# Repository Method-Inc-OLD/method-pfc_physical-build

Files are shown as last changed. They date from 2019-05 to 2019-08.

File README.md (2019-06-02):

# Method Personal Food Computer – Physical Build

Documentation of the mechanical and electrical design of [Method](Http://www.method.com)'s Personal Food Computer 

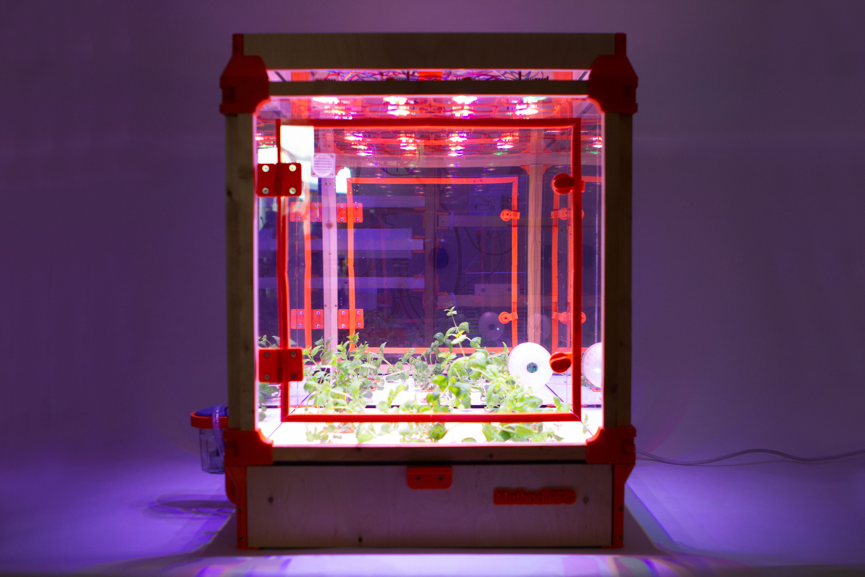
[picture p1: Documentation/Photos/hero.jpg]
mPFC v1.0


## Overview
The Method PFC is a version of OpenAg's Personal Food Computer. It was built to be more modular and incorporate recycled material. This repository contains:
- [Mechanical](/Mechanical) (Construction and 3D prints)
- [Electrical](/Electrical) (Circuitry)

For Method's custom software, please visit the [method-pfc_device-software](http://www.github.com/method-inc/method-pfc_device-software) repository.

## Credits

Method PFC v1.0 was designed and built by David Mayman, Felix Noller, Adrian Kraus, and Luke Thompson in London.

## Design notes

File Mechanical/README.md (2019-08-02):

# Mechanical

## Overview
The chassis is designed around a central 50cm3 acrylic chamber surrounded by a number of modules. All connectors are 3D printed, and all supporting materials are 21mm wood. This design makes it easy to grow or shrink the size of the box for revised designs or differently sized acrylic chambers. We recommend using tough filament. 

The PFC is designed with 4 modules: Bottom, Middle, Top, and Side. Each module has a number of 3D printed connectors. This repository contains 3D Rhino files with individual 3D print blocks, and assemblies for each module as well as one overall assembly.

### Modules
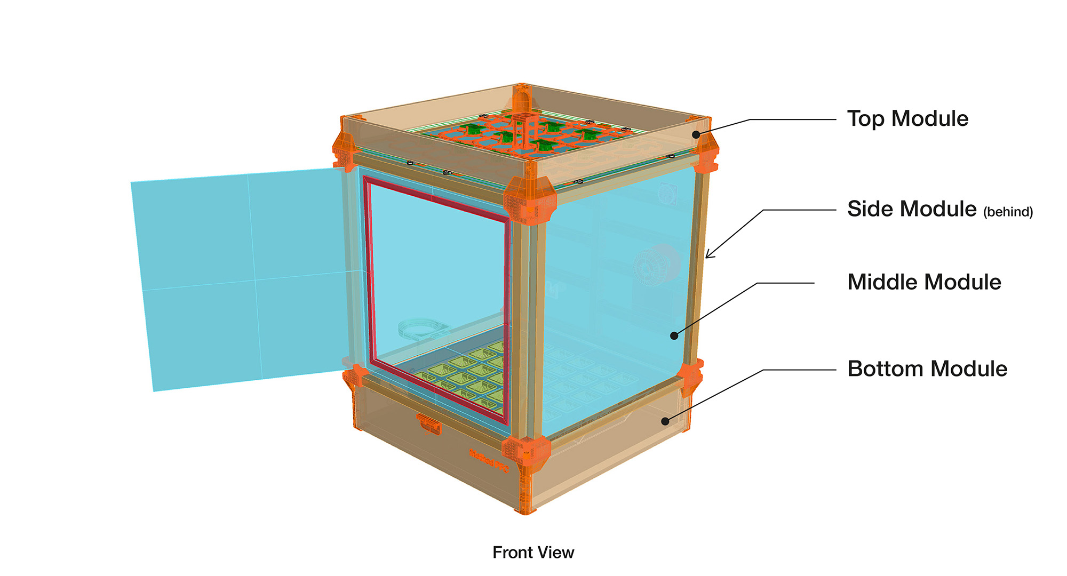
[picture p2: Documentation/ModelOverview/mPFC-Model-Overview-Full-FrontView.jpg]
Full Overview, Front

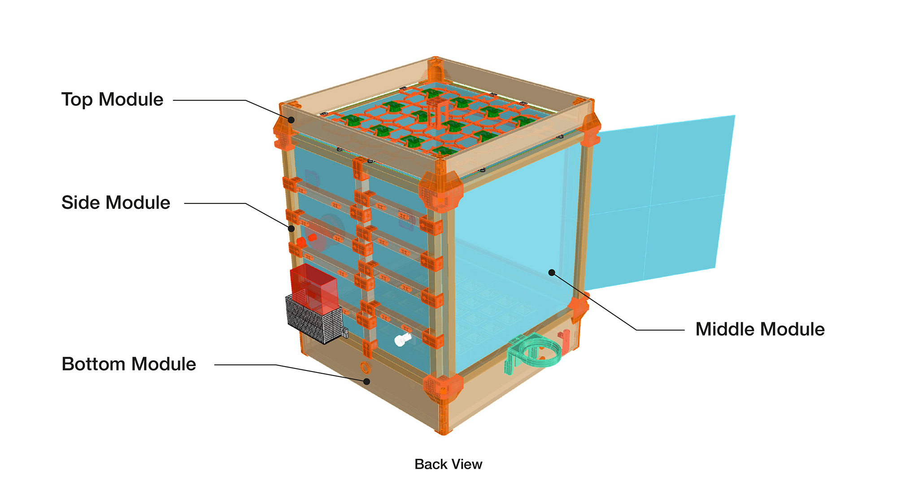
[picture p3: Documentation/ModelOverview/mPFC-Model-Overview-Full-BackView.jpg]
Back Overview, Front

Bottom module
- Component Overview
- Water reservoir
- Air pump
- 3 Atlas sensors (water temp, pH, EC)
- Heating modules glued to water reservoir (in retrospect, these are pretty useless. Most crops require colder water vs warmer.)
- “Feeding tube” / water level indicator
- Humidifier tank, tube, and mount

Middle Module
- Component Overview
- 50cm3 Acrylic chamber (we had one lying around…we realise this isn’t the cheapest item to source new)
- Opaque acrylic base plate to hold crops
- 1 Intake fan and 1 exhaust fan, with duct plates
- Circulation fan
- Air sensor bubble – CO2 and Temperature/humidity sensor
- Door with locks and hinges
- Base plate (for plants), laser-cut acrylic
- 2 way mirror film on the inside face of the acrylic chamber

Top module
- Component Overview
- 12 custom LED board assemblies (3 LEDs per board)
- Top view camera

Side module
- Component Overview
- Custom Mainboard (ended up not being so useful...see electronics)
- PSU
- 2 custom LED power boards (3 channels per)
- Beaglebone
- Arduino Mega
- Relay Board
- Breadboard
- A ton of wiring

## Guide to 3D Prints
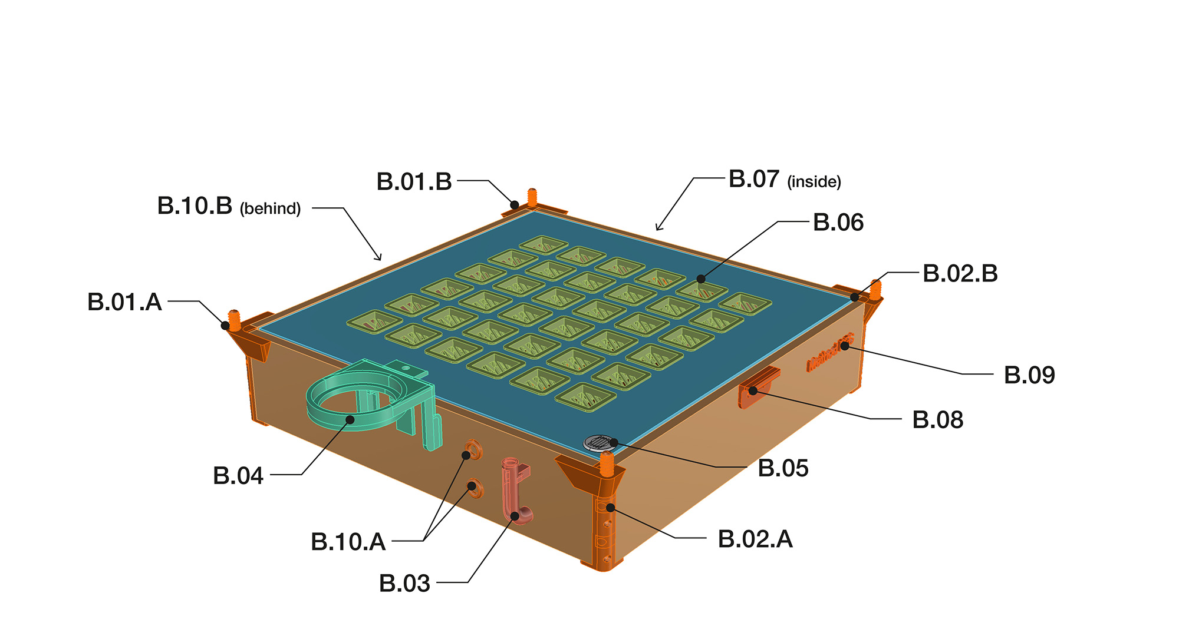
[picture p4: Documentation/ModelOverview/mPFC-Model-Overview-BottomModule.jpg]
Bottom Module Overview

### [Bottom module](/Mechanical/Bottom%20Module)
- B.01.A - Bottom Corner Connector, Left (1)
- B.01.B - Bottom Corner Connector, Right (1)
- B.02.A - Bottom Corner Connector, Door, Left (1)
- B.02.B - Bottom Corner Connector, Door, Right (1)
- B.03 - Feeding Tube Holder (1)
- B.04 - Humidifier Tank Mount (1)
- B.05 - Humidifier Mount (1) [2 versions]
- B.06 - Rockwool Carriage (4-12)
- B.07 - Atlas Sensor Holder (1)
- B.08 - Door Handle (1)
- B.09 - Name plate (1)
- B.10.A - Rivet, Small, for Tubing (2)
- B.10.B - Rivet, Large, for Wiring (1)
- B.11 - Safety Cover (1)
---

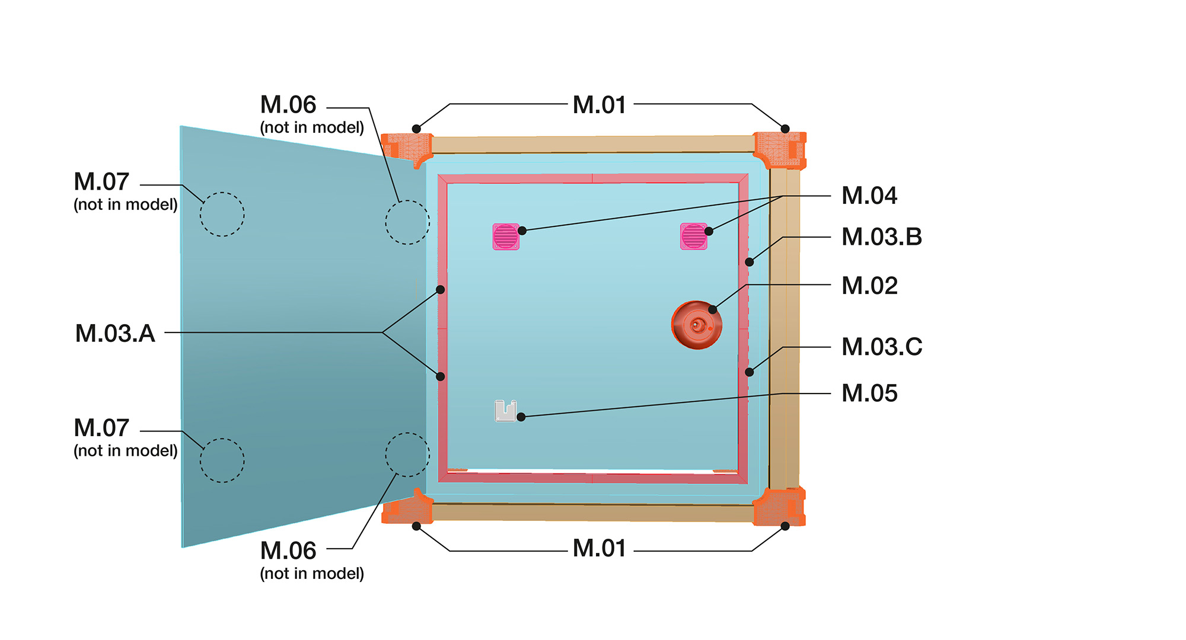
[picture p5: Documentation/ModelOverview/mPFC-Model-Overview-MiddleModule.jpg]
Middle Module Overview

### [Middle module](/Mechanical/Middle%20Module)
- M.01 - Middle Corner Connector (8)
- M.02 - Air Sensor Bubble (1)
- M.03.A - Frame Edge (6)
- M.03.B - Frame Edge, Top Right (1)
- M.03.C - Frame Edge, Bottom Right (1)
- M.04 - Fan Duct (2)
- M.05 - Circulation Fan Mount (1)
- M.06 - Door Hinge (2)
- M.07 - Door Lock (2) [Locking and handle versions]
---

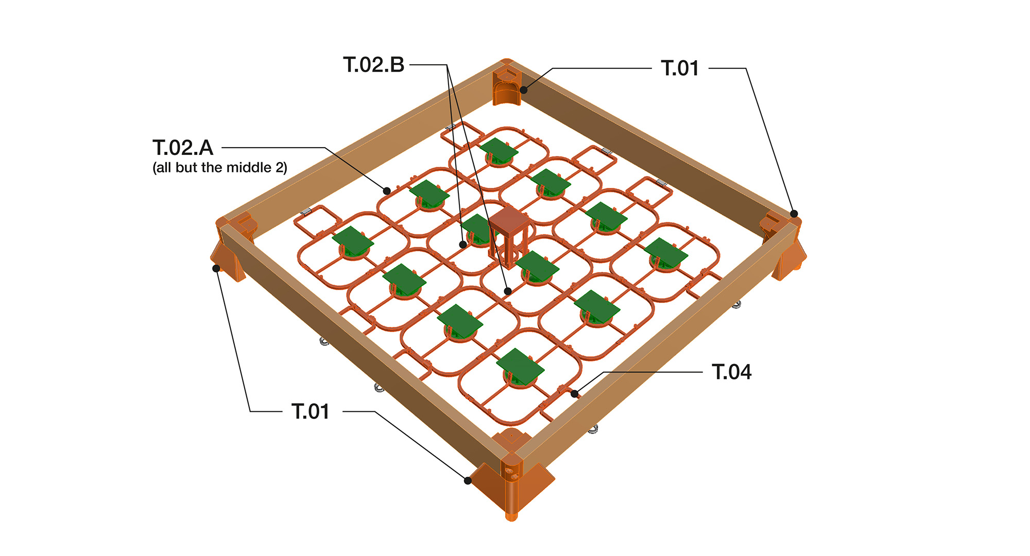
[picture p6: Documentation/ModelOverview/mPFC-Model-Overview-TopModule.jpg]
Top Module Overview

### [Top module](/Mechanical/Top%20Module)
- T.01 - Top Corner Connector (4)
- T.02.A - Lighting Board Mount (10)
- T.02.B - Lighting Board Mount, Camera Holder (2)
- T.03 - Middle Support Cap
- T.04 - Top Edge Spacer (8)
---

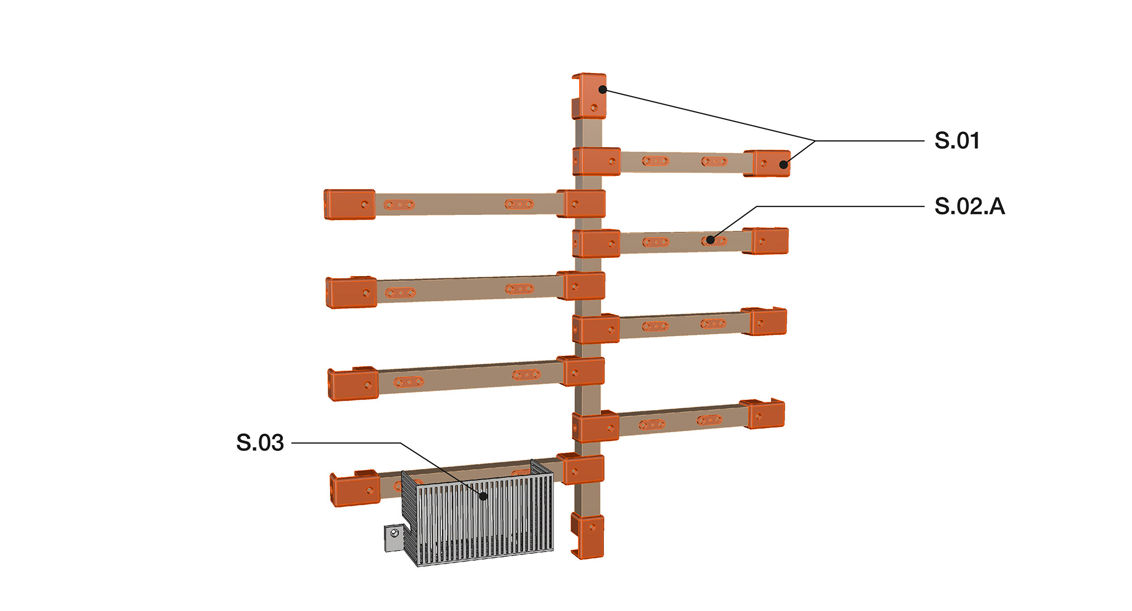
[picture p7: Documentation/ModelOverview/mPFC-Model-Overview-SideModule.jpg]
Side Module Overview

### [Side module](/Mechanical/Side%20Module)
- S.01 - Side Module Connector (16)
- S.02.A - Nut Holder (16)
- S.02.B - Nut Holder, Large (5)
- S.03 - Safety Cover (1)
---

### [Various](/Mechanical/Various)
- V.01 - Screw Nut (8)
- V.02 - Master Key (1)

## Credits

Method PFC v1.0 mechanical designed by Felix Noller and David Mayman

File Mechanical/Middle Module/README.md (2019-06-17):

# Middle Module

View these files as Rhino Source Files or STL files for 3D printing.

Middle Module Overview
- M.01 - Middle Corner Connector (8)
- M.02 - Air Sensor Bubble (1)
- M.03.A - Frame Edge (6)
- M.03.B - Frame Edge, Top Right (1)
- M.03.C - Frame Edge, Bottom Right (1)
- M.04 - Fan Duct (2)
- M.05 - Circulation Fan Mount (1)
- M.06 - Door Hinge (2)
- M.07 - Door Lock (2) [Locking and handle versions]

## Credits

Method PFC v1.0 mechanical designed by Felix Noller and David Mayman

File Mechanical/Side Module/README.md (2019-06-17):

# Side Module

View these files as Rhino Source Files or STL files for 3D printing.

Side Module Overview
- S.01 - Side Module Connector (16)
- S.02.A - Nut Holder (16)
- S.02.B - Nut Holder, Large (5)
- S.03 - Safety Cover (1)

## Credits

Method PFC v1.0 mechanical designed by Felix Noller and David Mayman

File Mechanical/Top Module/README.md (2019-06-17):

# Top Module

View these files as Rhino Source Files or STL files for 3D printing.

Top Module Overview
- T.01 - Top Corner Connector (4)
- T.02.A - Lighting Board Mount (10)
- T.02.B - Lighting Board Mount, Camera Holder (2)
- T.03 - Middle Support Cap
- T.04 - Top Edge Spacer (8)

## Credits

Method PFC v1.0 mechanical designed by Felix Noller and David Mayman

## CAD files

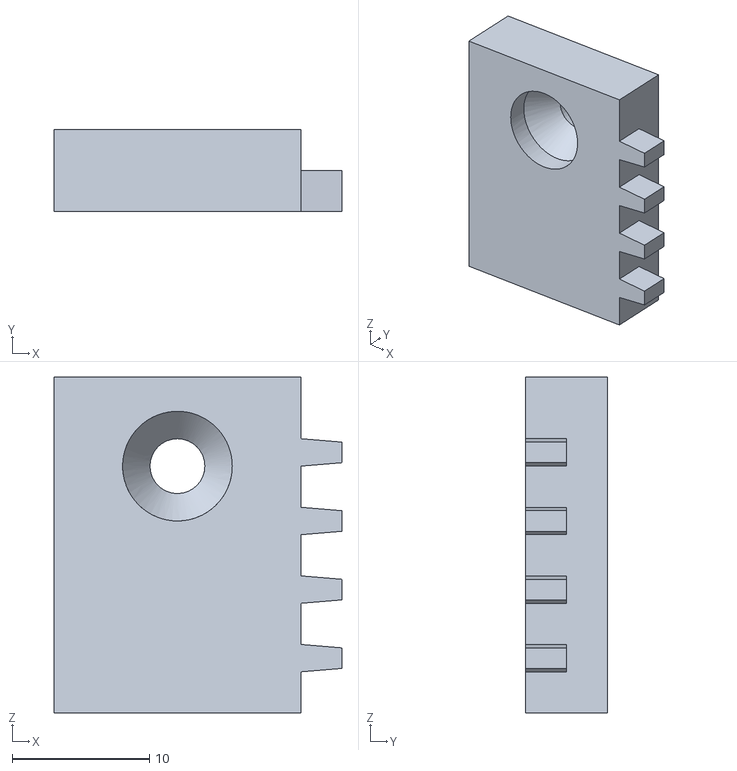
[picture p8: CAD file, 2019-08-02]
Mechanical/Bottom Module/STL for 3D Printing/B.11 - Bottom Module – Safety Cover – Mount Piece L.stl
21.0 x 6.00 x 24.5

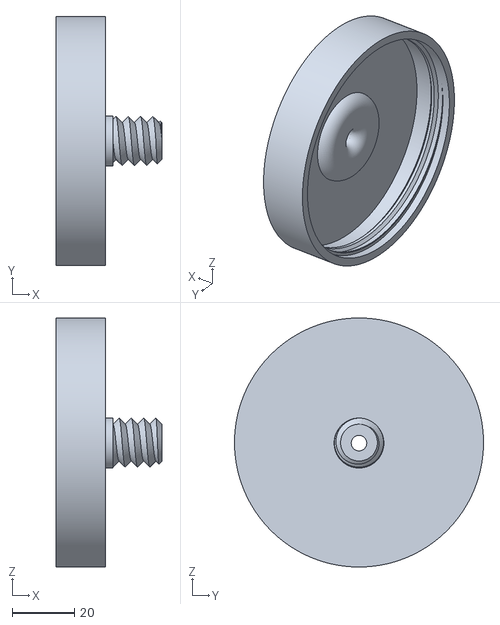
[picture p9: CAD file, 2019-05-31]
Mechanical/Middle Module/STL for 3D printing/M.02 - Air Sensor Bubble (2 of 3).stl
34.1 x 80.0 x 80.0

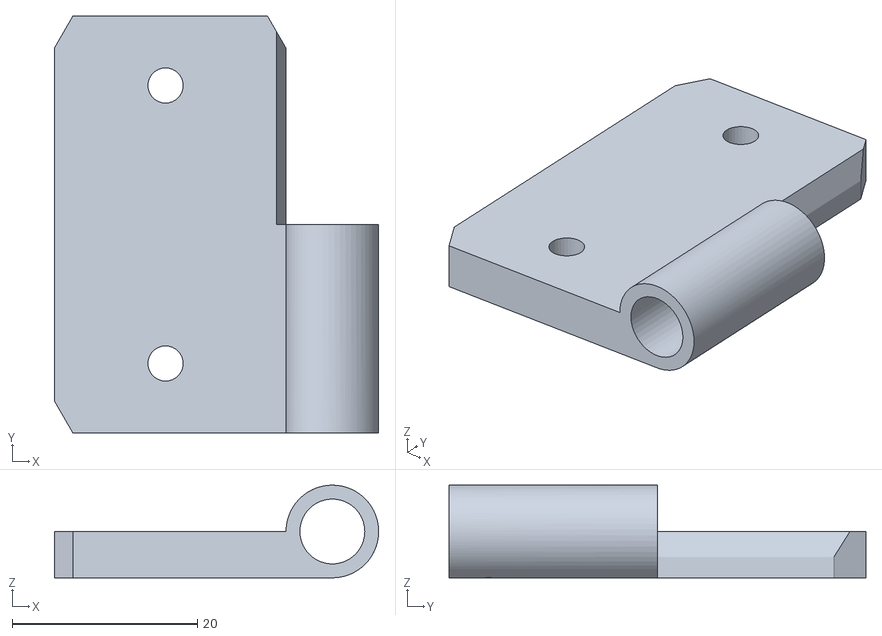
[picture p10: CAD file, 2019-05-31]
Mechanical/Middle Module/STL for 3D printing/M.06 - Door Hinge/files/hinge_frame_side.stl
35.0 x 45.0 x 10.00

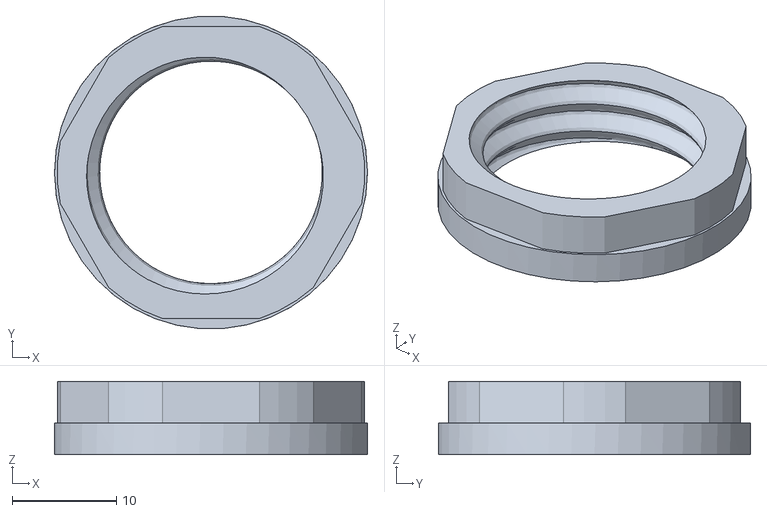
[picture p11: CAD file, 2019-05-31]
Mechanical/Middle Module/STL for 3D printing/M.07 - Door Lock /files/Fecho_002.stl
30.0 x 29.9 x 7.00

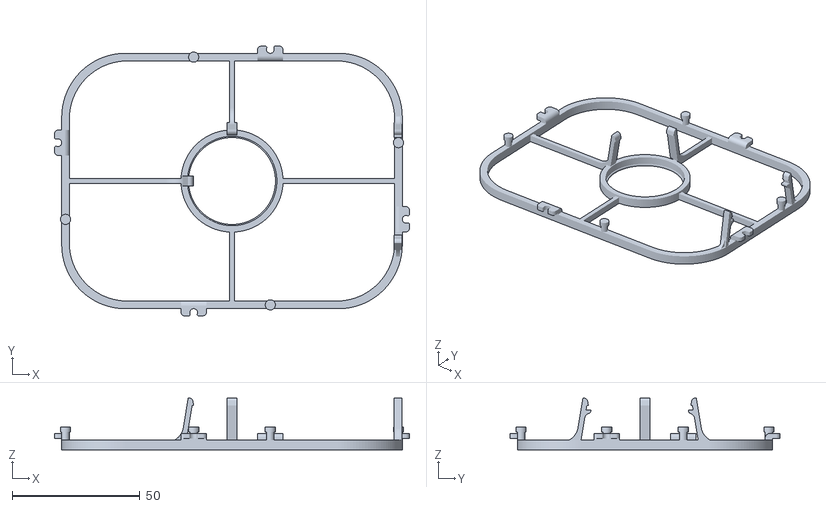
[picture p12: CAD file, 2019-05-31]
Mechanical/Top Module/STL for 3D Printing/T.02.C - Lighting Board Mount, LED Driver Holder.stl
139.0 x 105.6 x 20.3

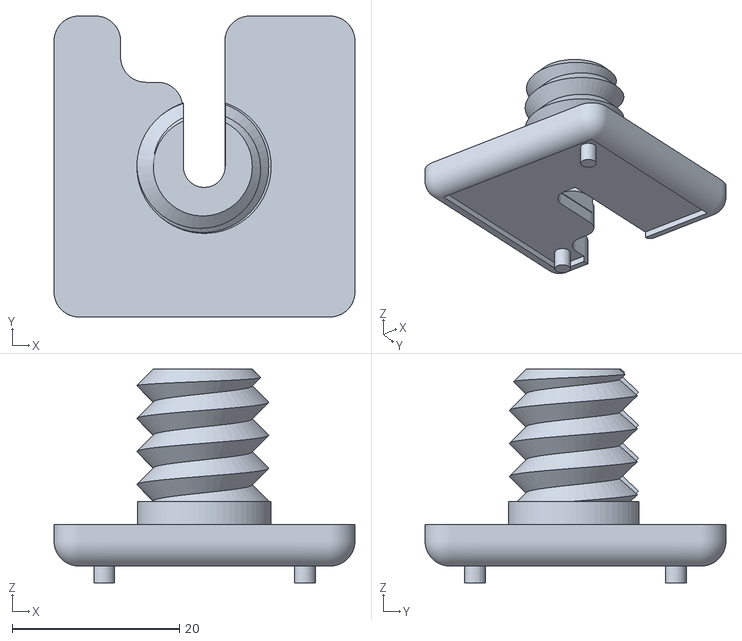
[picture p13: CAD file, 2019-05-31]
Mechanical/Middle Module/STL for 3D printing/M.05 - Circulation Fan Mount (1 of 2).stl
36.0 x 36.0 x 25.6

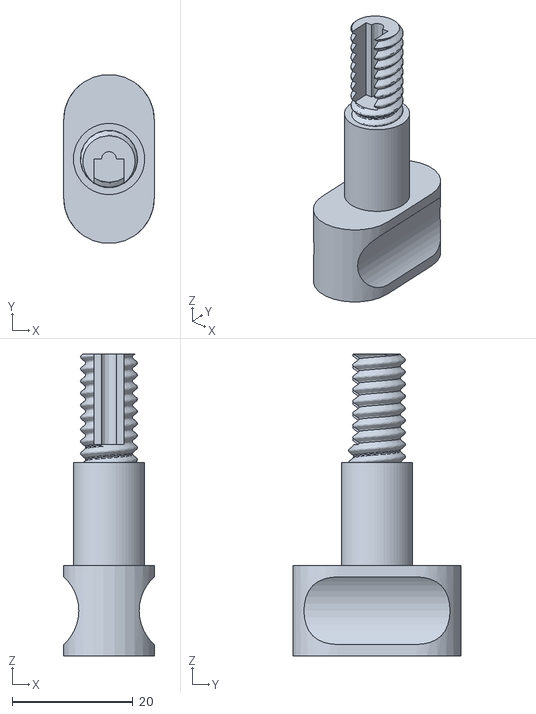
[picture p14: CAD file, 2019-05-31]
Mechanical/Middle Module/STL for 3D printing/M.07 - Door Lock /files/Fecho_003-16-DM.stl
15.0 x 27.9 x 50.0

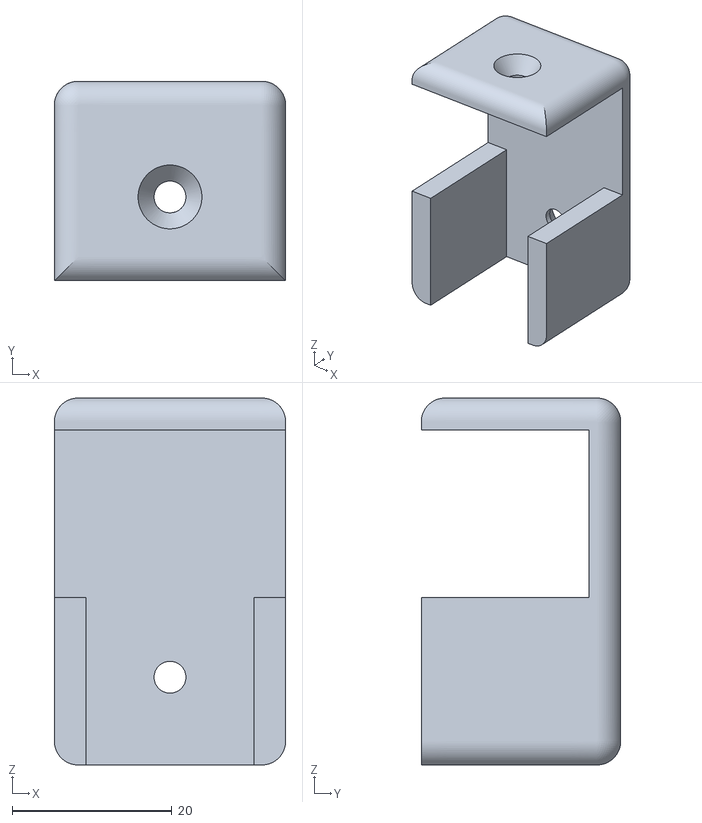
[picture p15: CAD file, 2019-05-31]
Mechanical/Side Module/STL for 3D Printing/S.01 - Side Module Connector.stl
29.0 x 25.0 x 46.0

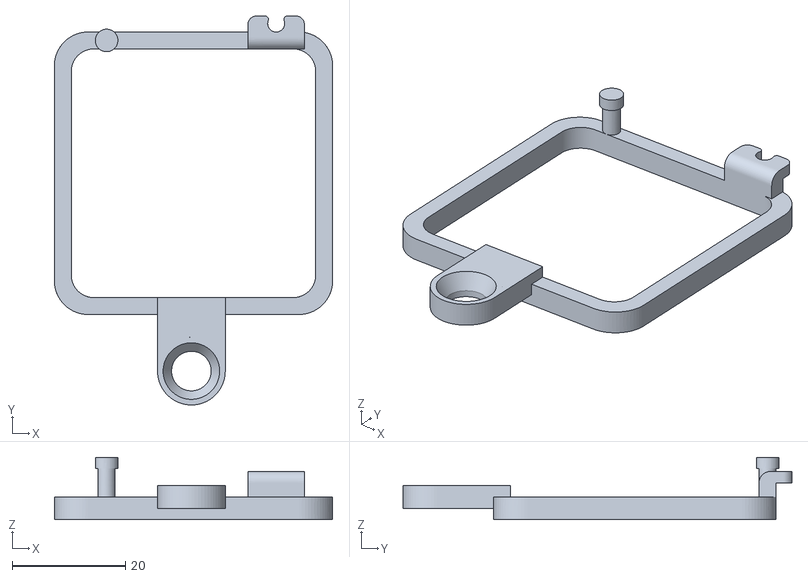
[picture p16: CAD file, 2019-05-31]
Mechanical/Top Module/STL for 3D Printing/T.04 - Top Edge Spacer.stl
49.2 x 68.8 x 11.0

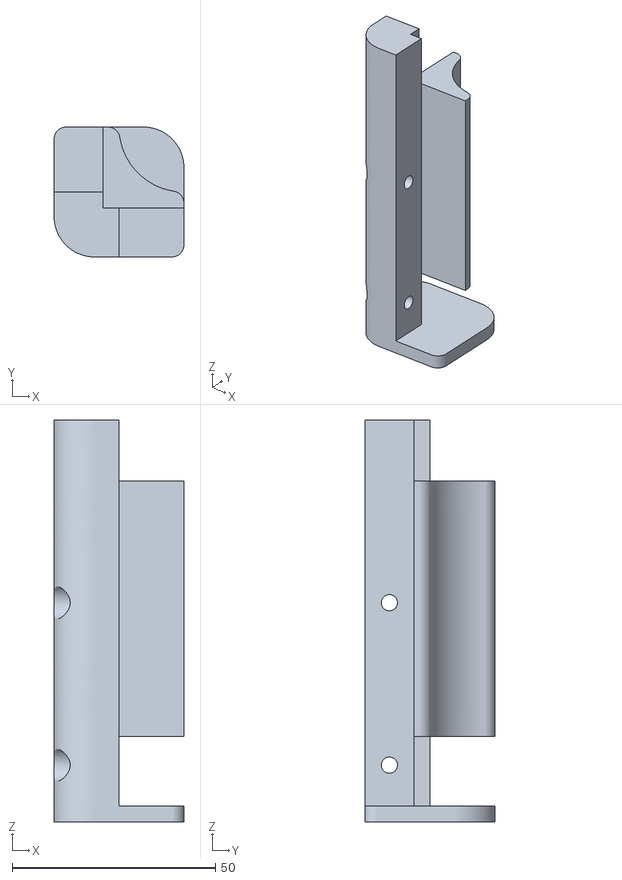
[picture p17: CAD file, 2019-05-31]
Mechanical/Bottom Module/STL for 3D Printing/B.02.B - Bottom Corner Connector, Door, Right (2 of 2).stl
32.0 x 32.0 x 99.0

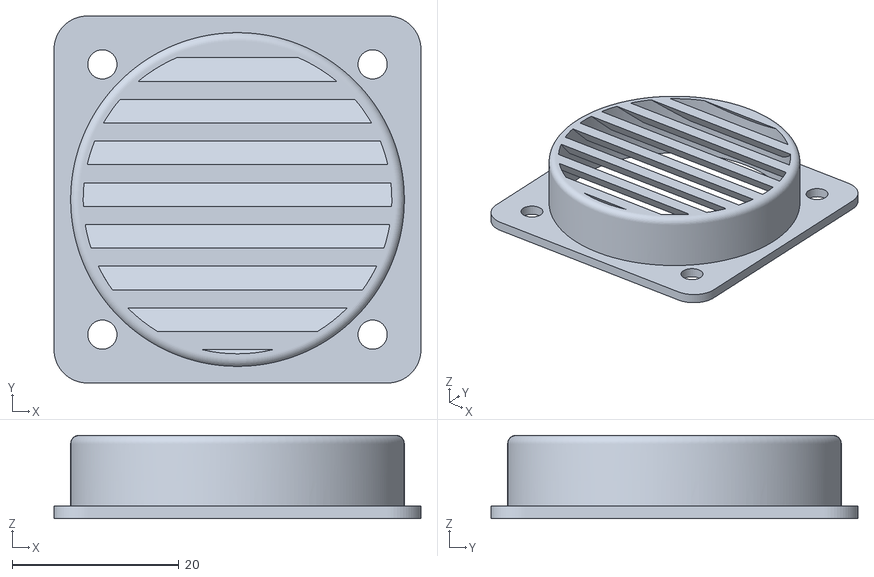
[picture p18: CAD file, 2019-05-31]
Mechanical/Middle Module/STL for 3D printing/M.04 - Fan Duct.stl
44.0 x 44.0 x 10.0

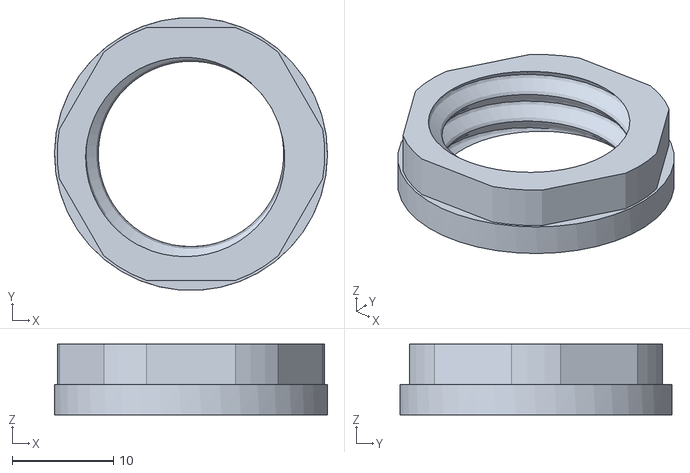
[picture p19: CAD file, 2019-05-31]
Mechanical/Middle Module/STL for 3D printing/M.07 - Door Lock /files/Fecho_002-18.stl
27.0 x 26.9 x 7.00

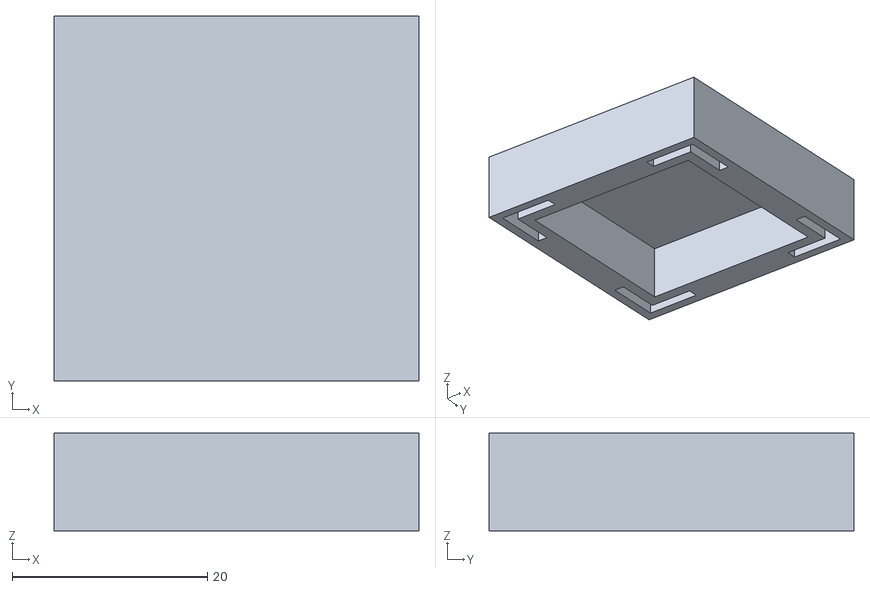
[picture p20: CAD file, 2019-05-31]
Mechanical/Top Module/STL for 3D Printing/T.03 - Middle Support Cap.stl
37.4 x 37.4 x 10.0

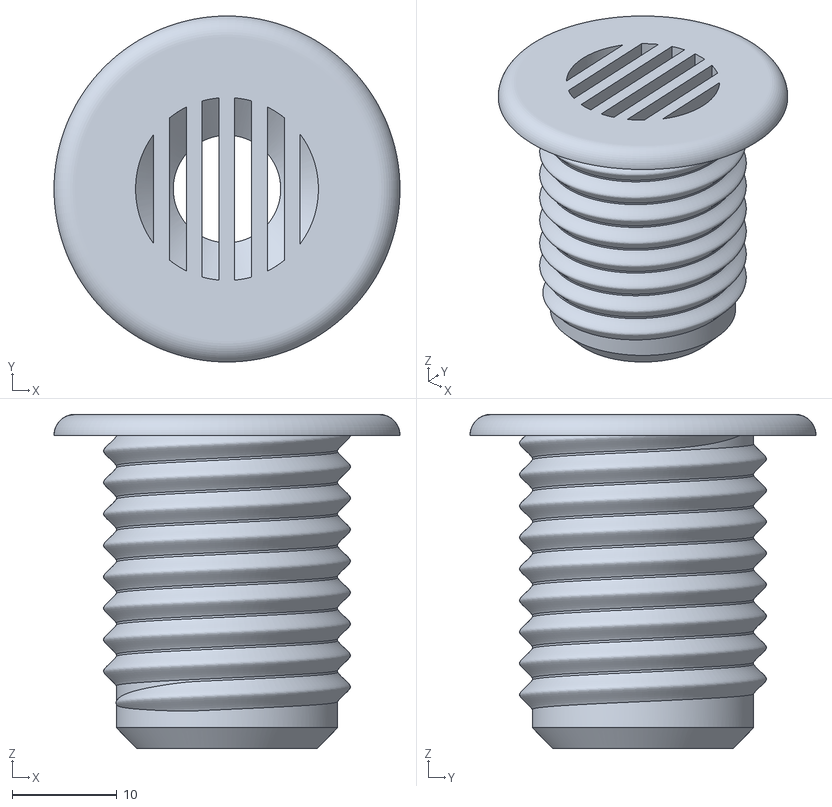
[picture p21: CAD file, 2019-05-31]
Mechanical/Bottom Module/STL for 3D Printing/B.05v2 - Humidifier Mount (1 of 2).stl
33.0 x 33.0 x 31.9

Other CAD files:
Mechanical/Side Module/STL for 3D Printing/S.03 - Safety Cover (3 of 3).stl
Mechanical/Bottom Module/STL for 3D Printing/B.11 - Bottom Module – Safety Cover – Mount Piece R.stl
Mechanical/Middle Module/STL for 3D printing/M.06 - Door Hinge/files/hinge_door_side.stl
Mechanical/Middle Module/STL for 3D printing/M.05 - Circulation Fan Mount (2 of 2).stl
Mechanical/Bottom Module/Rhino Source Files/B.01.A - Bottom Corner Connector, Left.3dm
Mechanical/Bottom Module/Rhino Source Files/B.01.B - Bottom Corner Connector, Right.3dm
Mechanical/Bottom Module/Rhino Source Files/B.010.A - Rivet, Small, for Tubing.3dm
Mechanical/Bottom Module/Rhino Source Files/B.04 - Humidifier Tank Mount.3dm
Mechanical/Bottom Module/Rhino Source Files/B.07 - Atlas Sensor Holder.3dm
Mechanical/Bottom Module/Rhino Source Files/B.08 - Door Handle.3dm
Mechanical/Bottom Module/Rhino Source Files/B.09 - Name plate.3dm
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

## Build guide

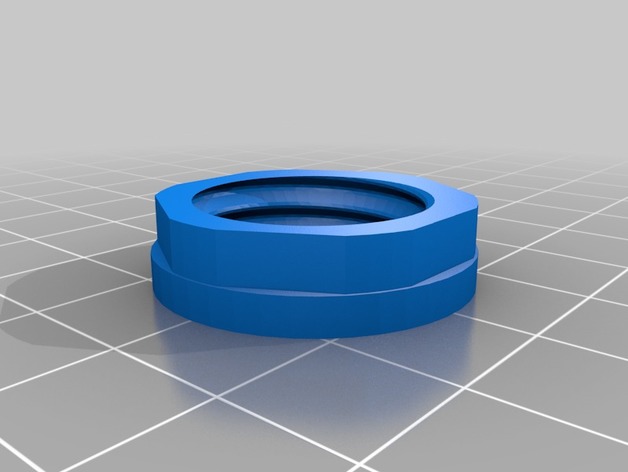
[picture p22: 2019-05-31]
Mechanical/Middle Module/STL for 3D printing/M.07 - Door Lock /images/54c15d861ea556b41e938c578dfb2fad_preview_featured.jpg

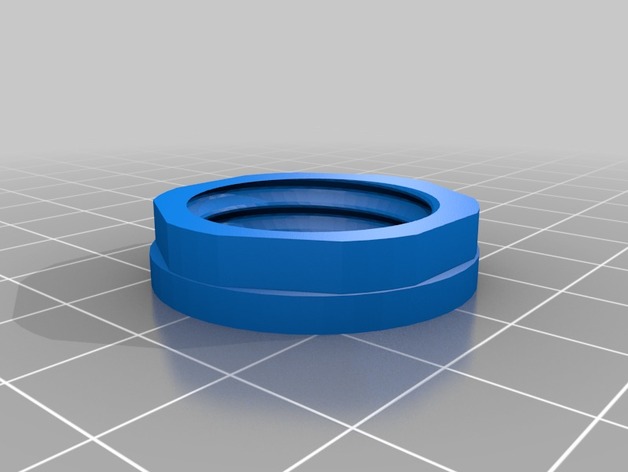
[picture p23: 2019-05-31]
Mechanical/Middle Module/STL for 3D printing/M.07 - Door Lock /images/dfc39821333d006078d451c76782461f_preview_featured.jpg

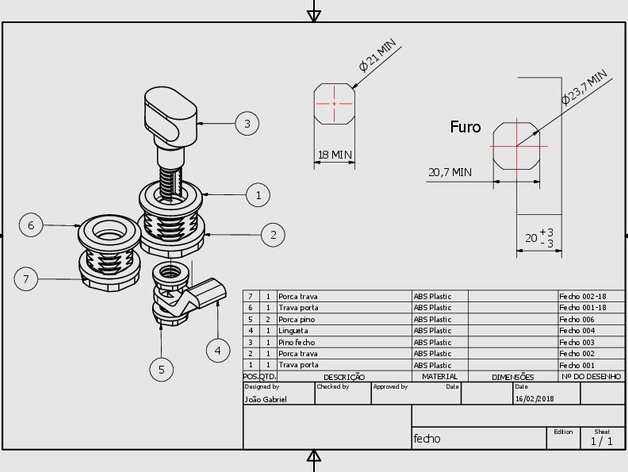
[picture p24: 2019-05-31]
Mechanical/Middle Module/STL for 3D printing/M.07 - Door Lock /images/2d46e0b6e0e16649fa4b66adb6a0845b_preview_featured.jpg

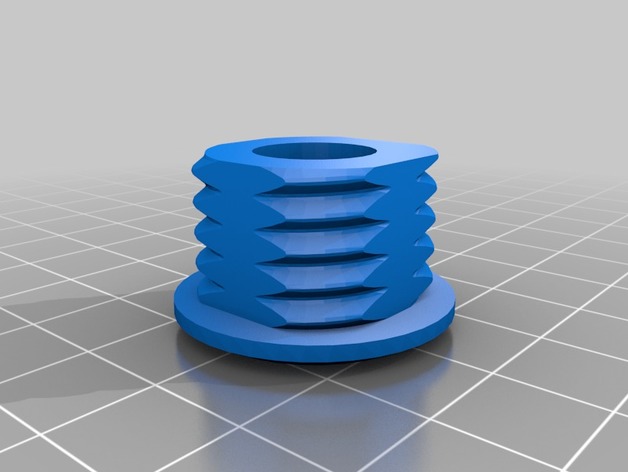
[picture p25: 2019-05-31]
Mechanical/Middle Module/STL for 3D printing/M.07 - Door Lock /images/17674acc5ccf1f13b2d2eec718898e9f_preview_featured.jpg

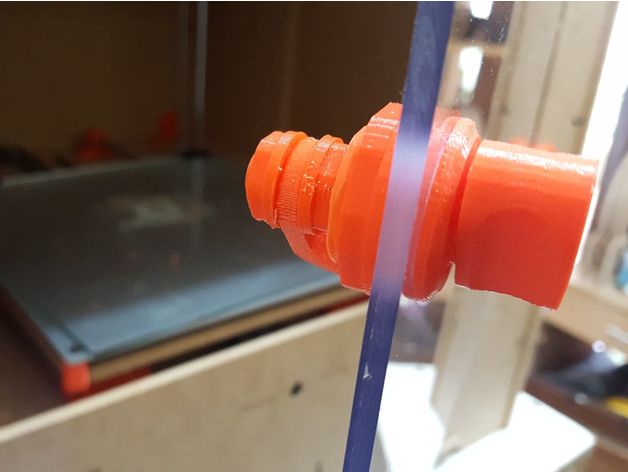
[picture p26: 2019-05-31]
Mechanical/Middle Module/STL for 3D printing/M.07 - Door Lock /images/0e23cded5c8427db39357190bee45d2e_preview_featured.jpg

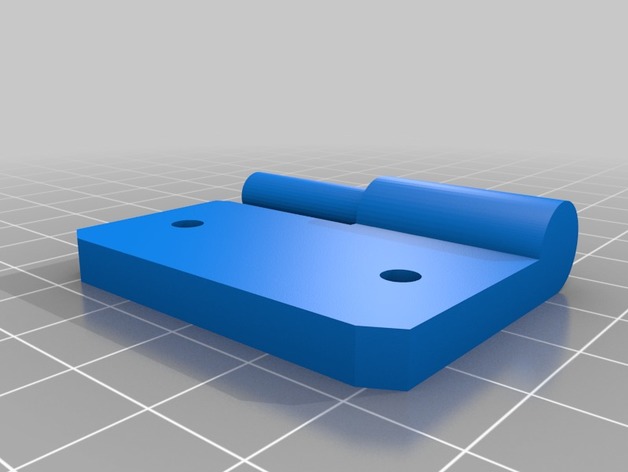
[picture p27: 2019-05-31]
Mechanical/Middle Module/STL for 3D printing/M.06 - Door Hinge/images/cf1e8f1d2e79c848e55293c628ae8979_preview_featured.jpg

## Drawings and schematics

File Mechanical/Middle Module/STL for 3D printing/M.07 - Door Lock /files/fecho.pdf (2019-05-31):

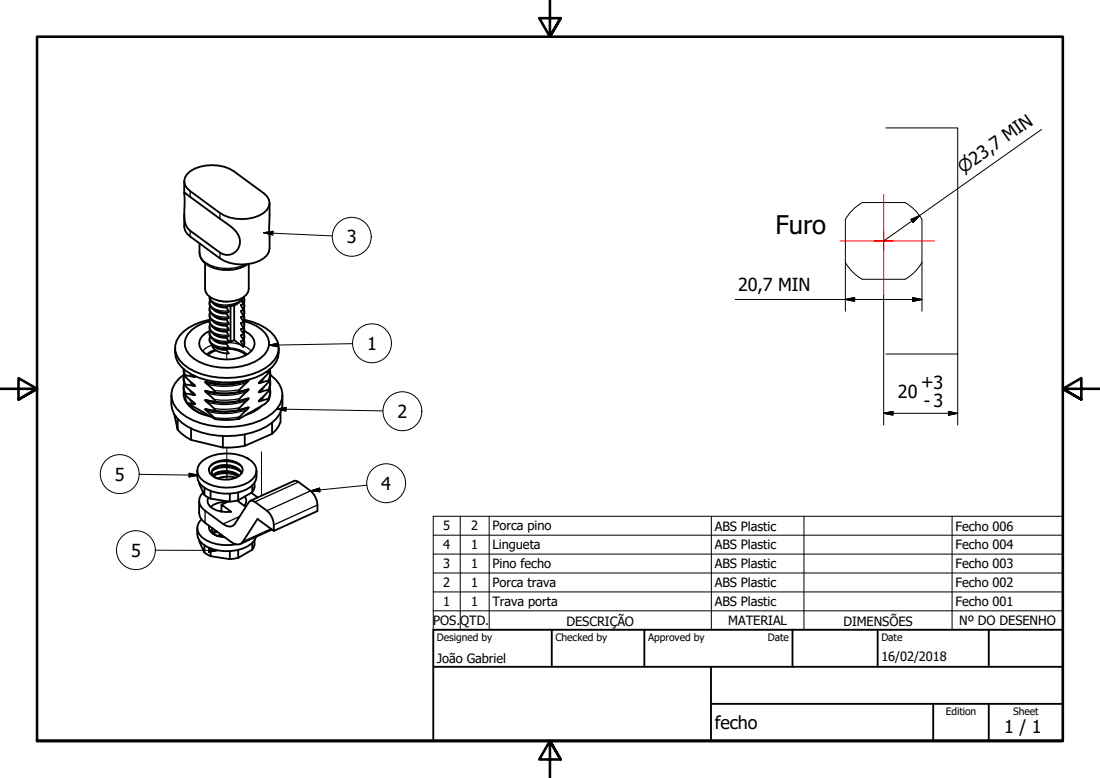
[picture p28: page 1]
20,7 MIN

5 | 2 | Porca pino | ABS Plastic | | Fecho 006
4 | 1 | Lingueta | ABS Plastic | | Fecho 004
3 | 1 | Pino fecho | ABS Plastic | | Fecho 003
2 | 1 | Porca trava | ABS Plastic | | Fecho 002
1 | 1 | Trava porta | ABS Plastic | | Fecho 001
POS.QTD. | | DESCRId-O | MATERIAL | DIMENS®ES | N DO DESENHO
Designed by Jomo Gabriel | Checked by | Approved by Date | | Date 16/02/2018

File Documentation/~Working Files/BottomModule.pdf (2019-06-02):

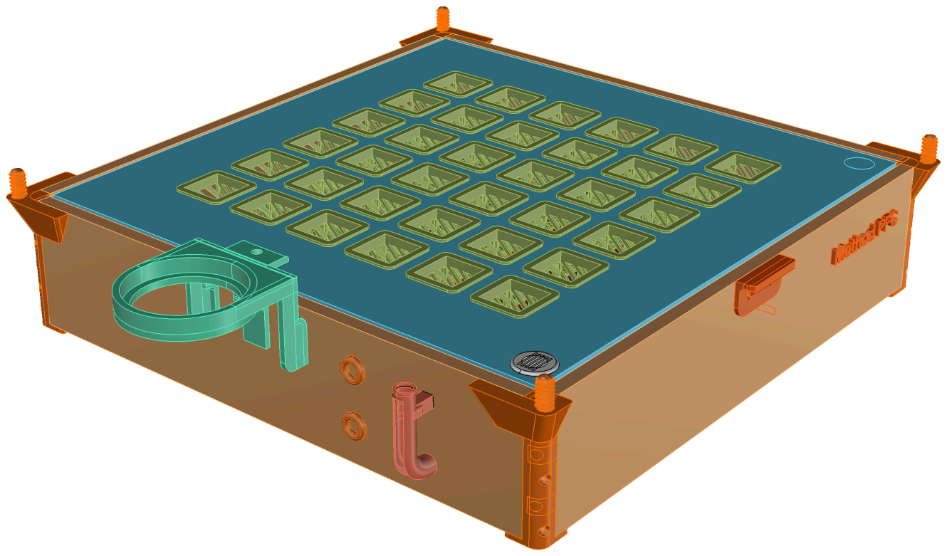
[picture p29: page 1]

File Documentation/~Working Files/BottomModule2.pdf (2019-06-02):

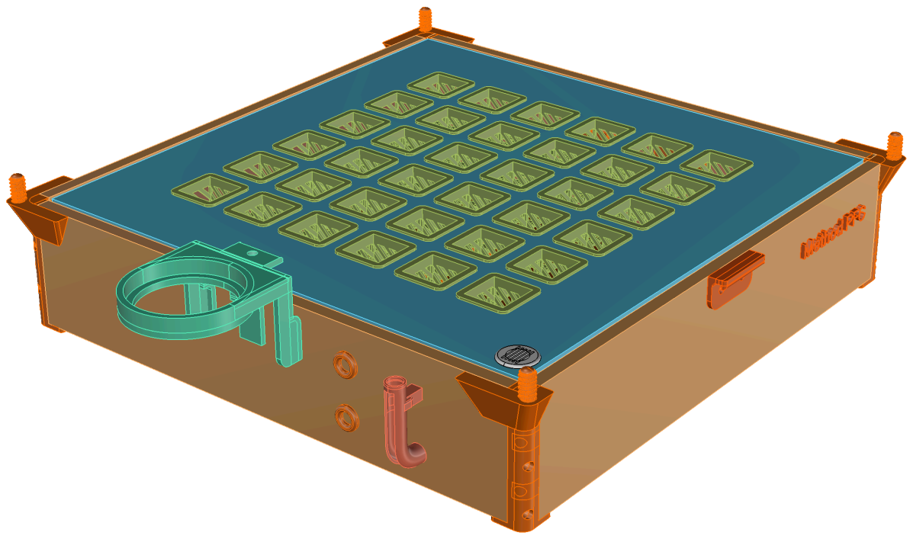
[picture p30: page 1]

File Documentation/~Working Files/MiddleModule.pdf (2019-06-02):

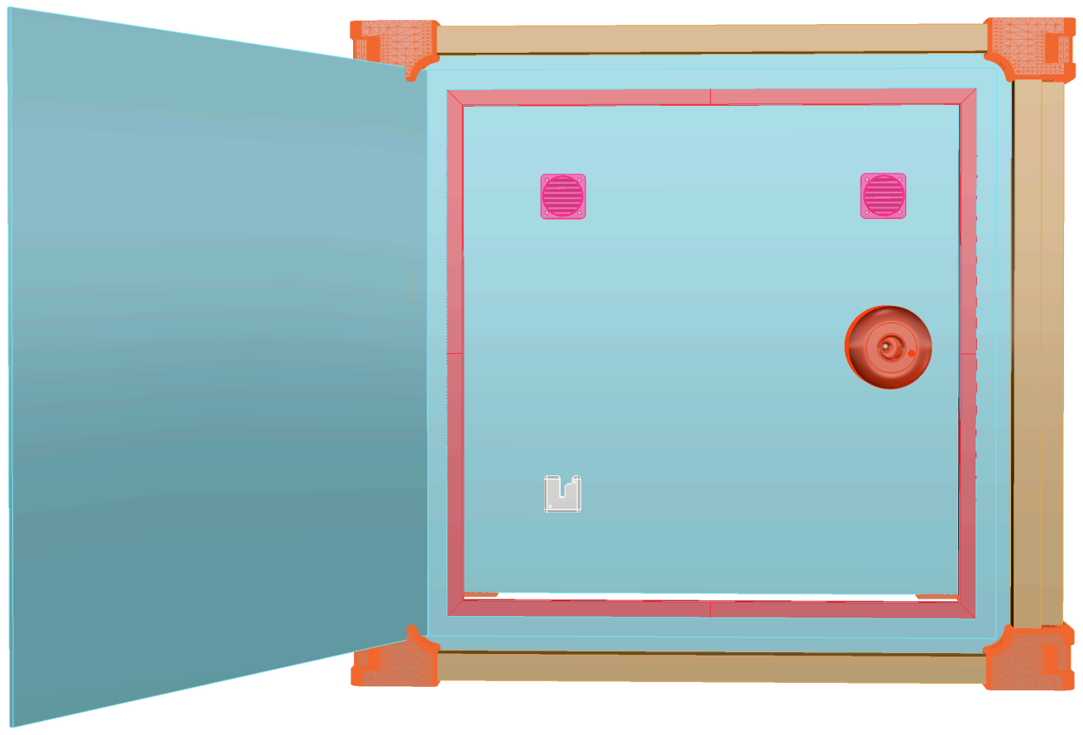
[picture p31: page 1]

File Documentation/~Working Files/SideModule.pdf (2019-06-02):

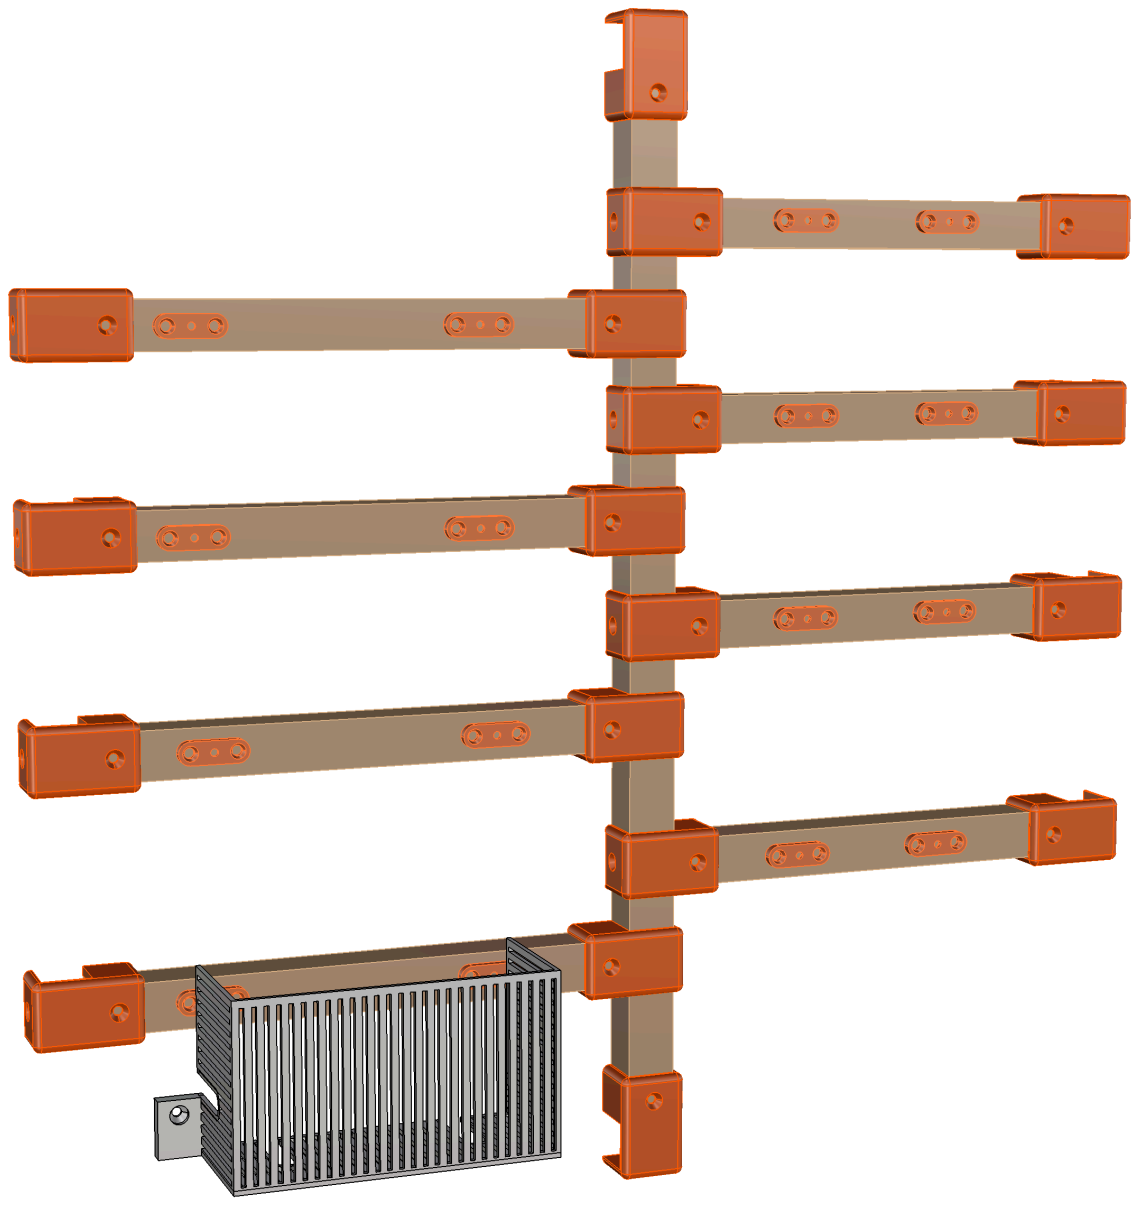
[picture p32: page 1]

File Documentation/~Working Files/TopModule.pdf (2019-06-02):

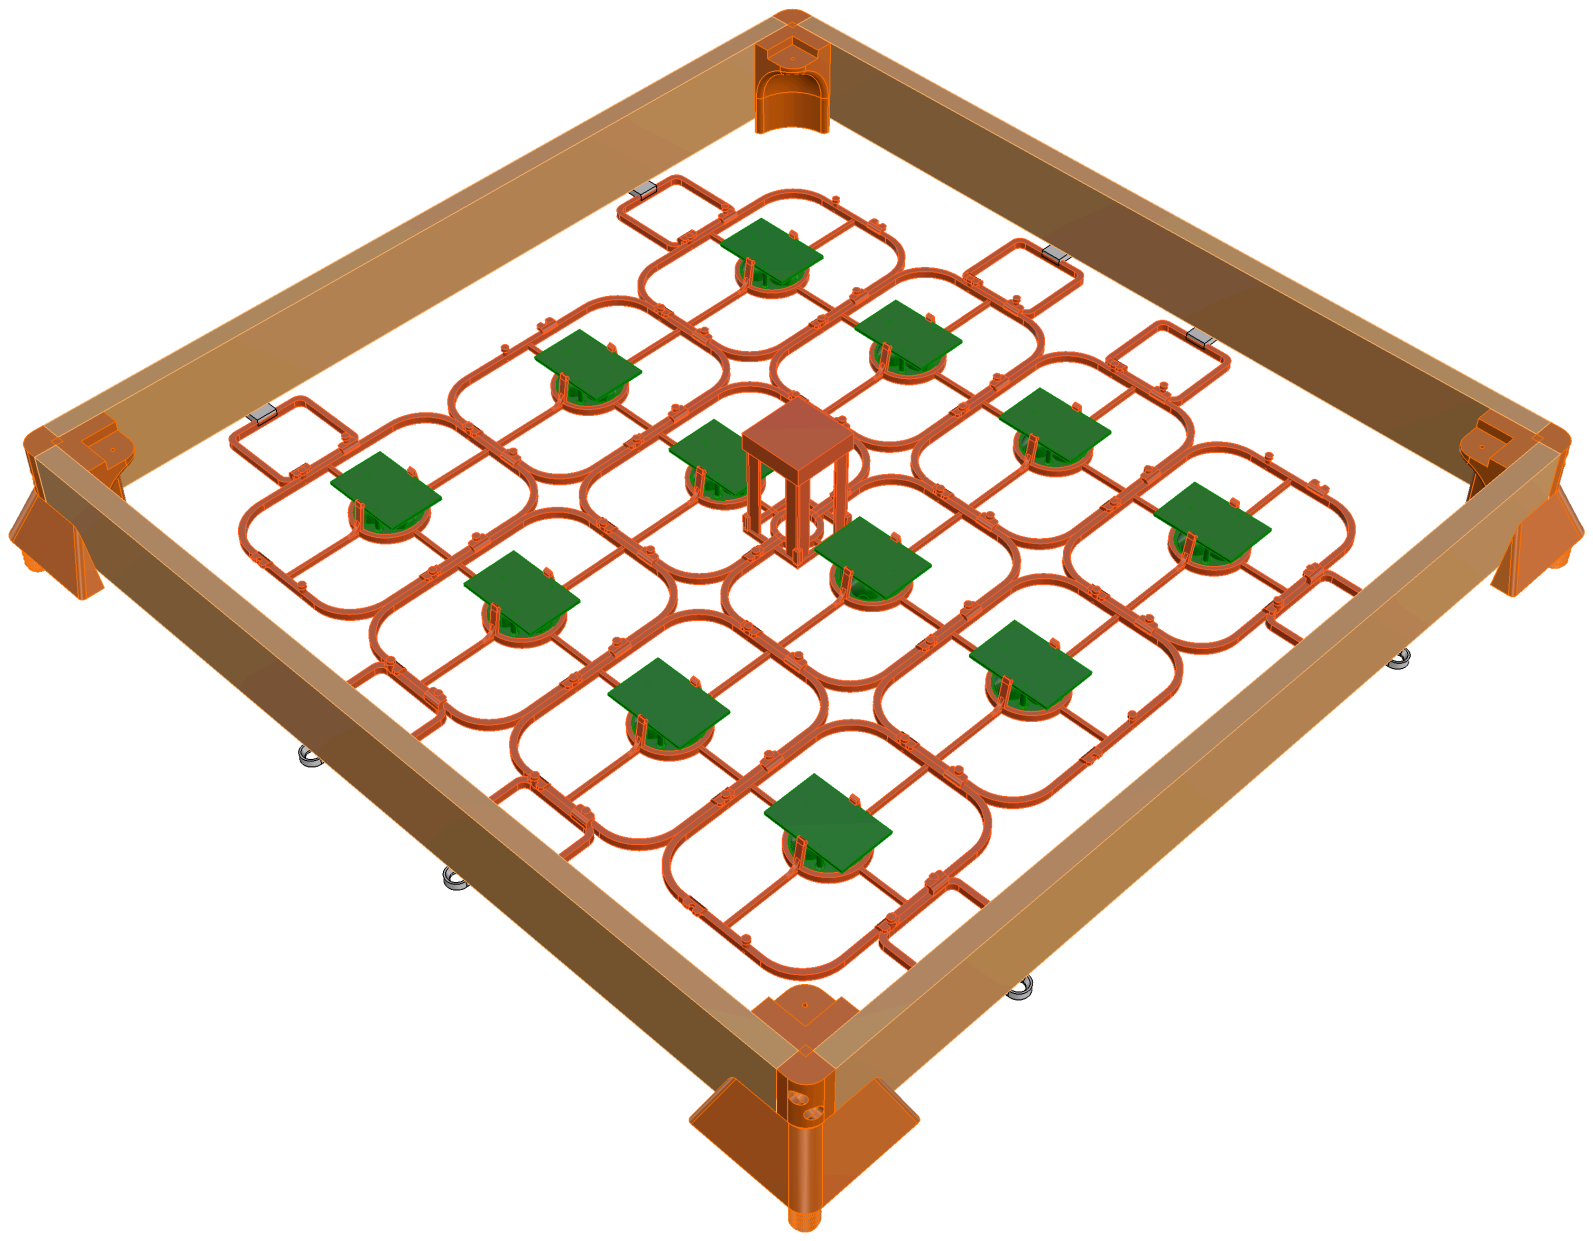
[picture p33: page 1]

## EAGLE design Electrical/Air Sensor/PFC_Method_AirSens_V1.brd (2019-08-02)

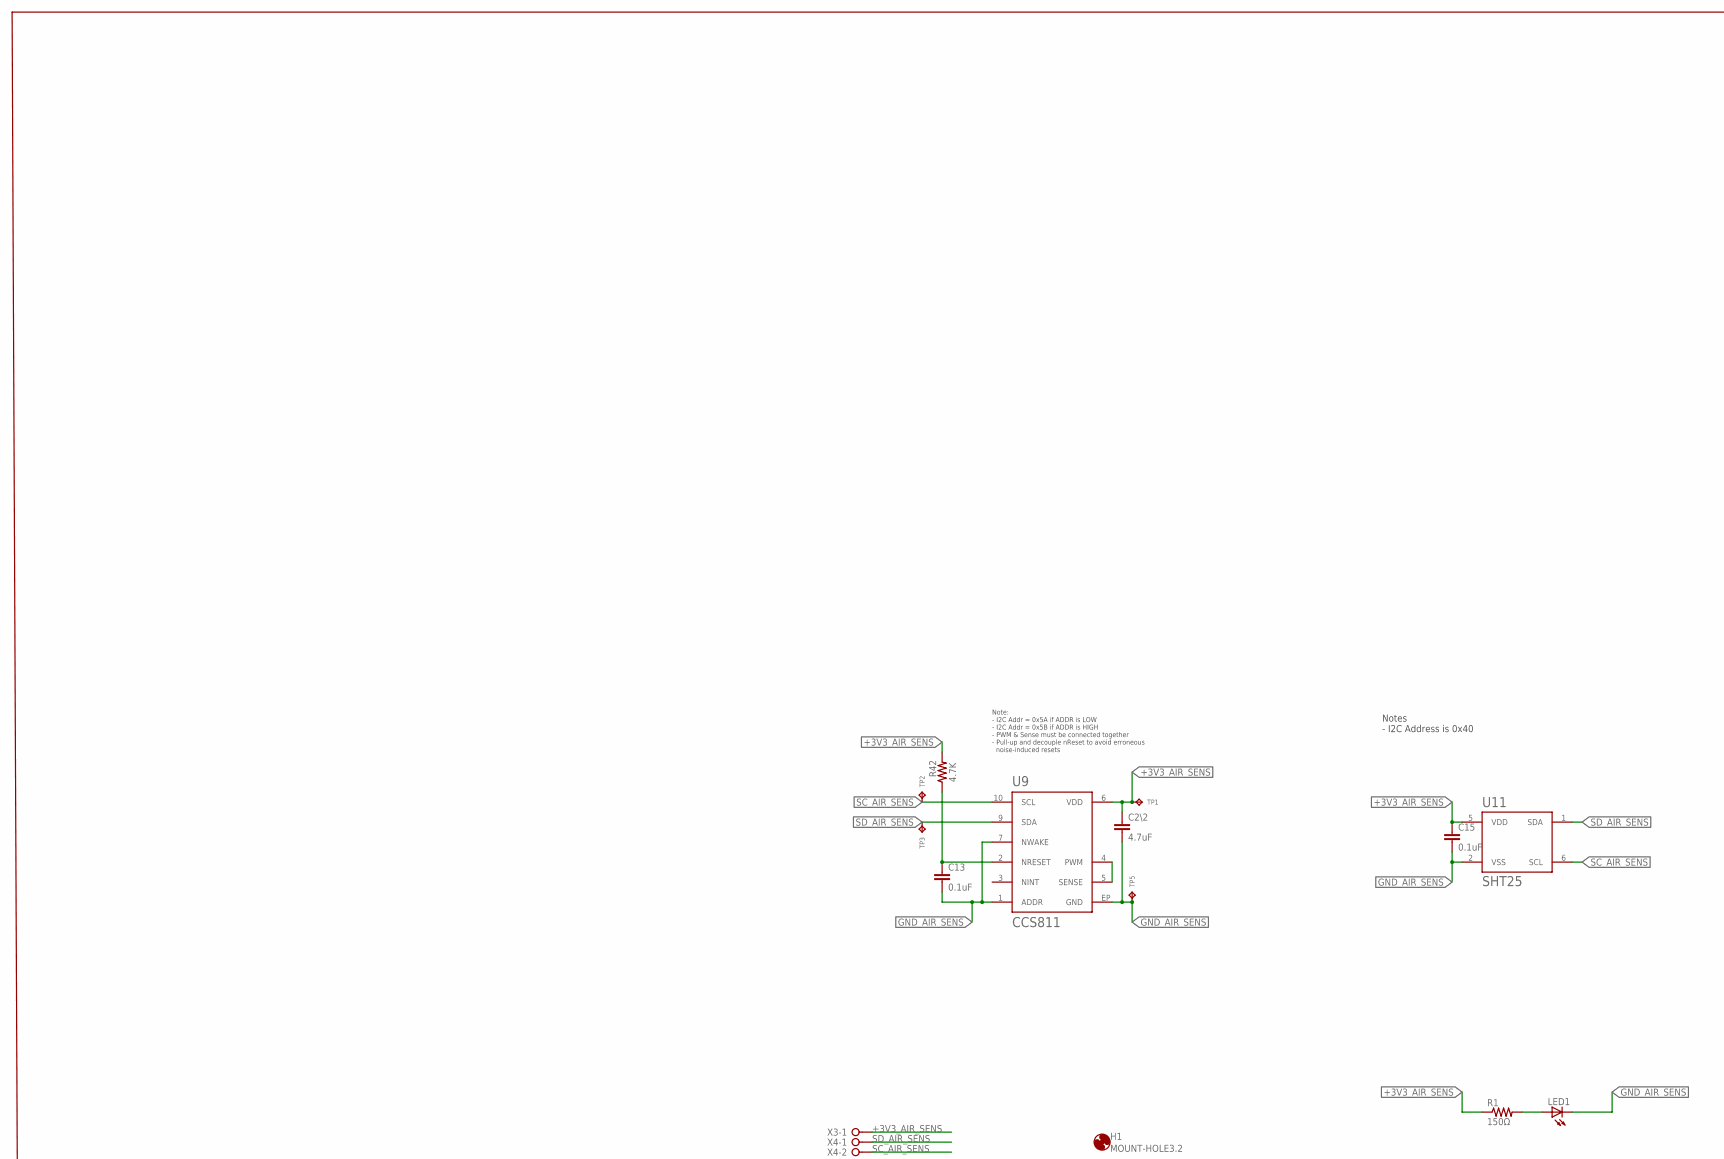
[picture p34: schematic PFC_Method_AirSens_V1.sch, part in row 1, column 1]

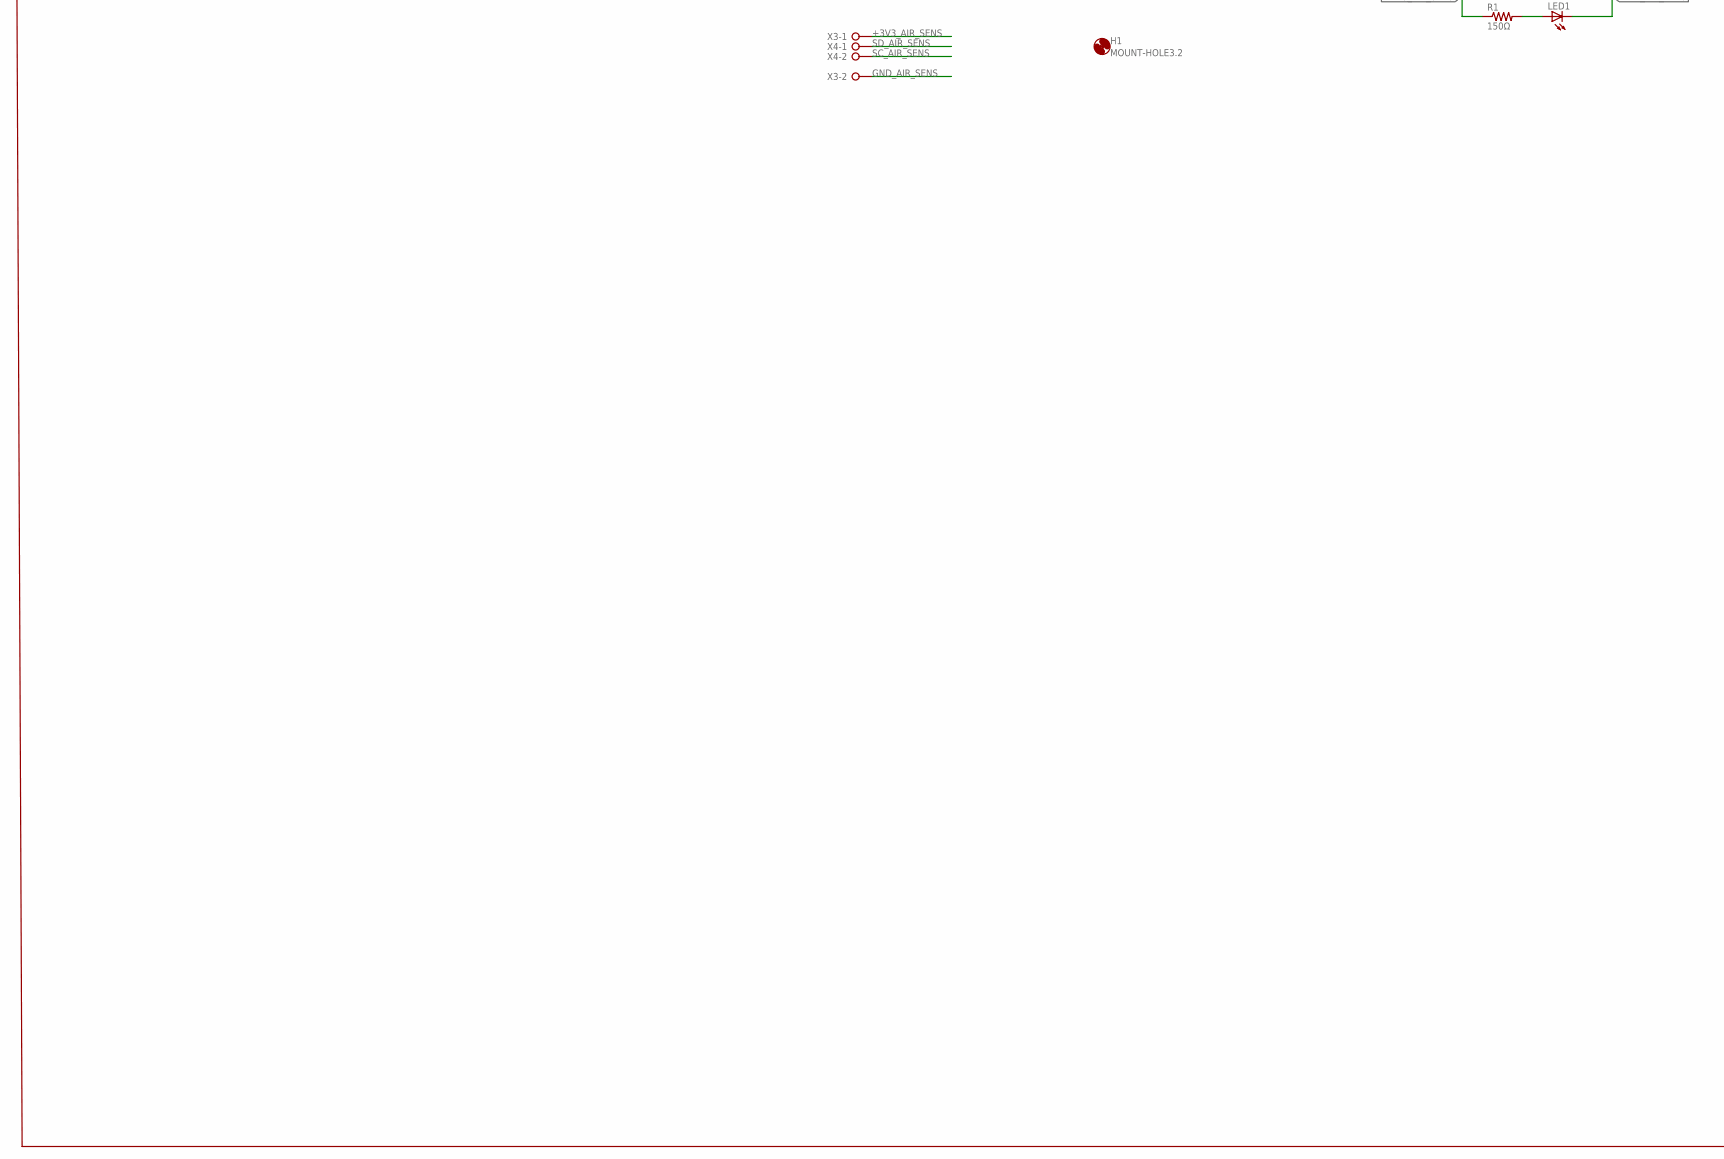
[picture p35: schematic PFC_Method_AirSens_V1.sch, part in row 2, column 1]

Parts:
C2\2: 4.7uF; C0805
C13, C15: 0.1uF; C0603
H1: MOUNT-HOLE3.2; 3,2
LED1: LED5MM
R1: 150Ω; 0207/10
R42: 4.7K; R1206
TP1, TP2, TP3, TP5: TPTP06R; TP06R
U9: CCS811
U11: SHT25; SHT2X
X3, X4: W237-02P; W237-132

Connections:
+3V3_AIR_SENS: C2\2.1, C15.1, R1.1, R42.2, TP1.TP, U9.6 (VDD), U11.5 (VDD), X3.1
GND_AIR_SENS: C2\2.2, C13.2, C15.2, LED1.K (C), TP5.TP, U9.1 (ADDR), U9.7 (NWAKE), U9.EP (GND), U11.2 (VSS), X3.2
unnamed: LED1.A, R1.2
unnamed: U9.4 (PWM), U9.5 (SENSE)
unnamed: C13.1, R42.1, U9.2 (NRESET)
SC_AIR_SENS: TP2.TP, U9.10 (SCL), U11.6 (SCL), X4.2
SD_AIR_SENS: TP3.TP, U9.9 (SDA), U11.1 (SDA), X4.1

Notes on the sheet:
Original Board by Dan Poitrast
Change Log:
Released under the Creative Commons Attribution Share-Alike 4.0 License https://creativecommons.org/licenses/by-sa/4.0/
Note: - I2C Addr = 0x5A if ADDR is LOW - I2C Addr = 0x5B if ADDR is HIGH - PWM & Sense must be connected together - Pull-up and decouple nReset to avoid erroneous noise-induced resets
Notes - I2C Address is 0x40

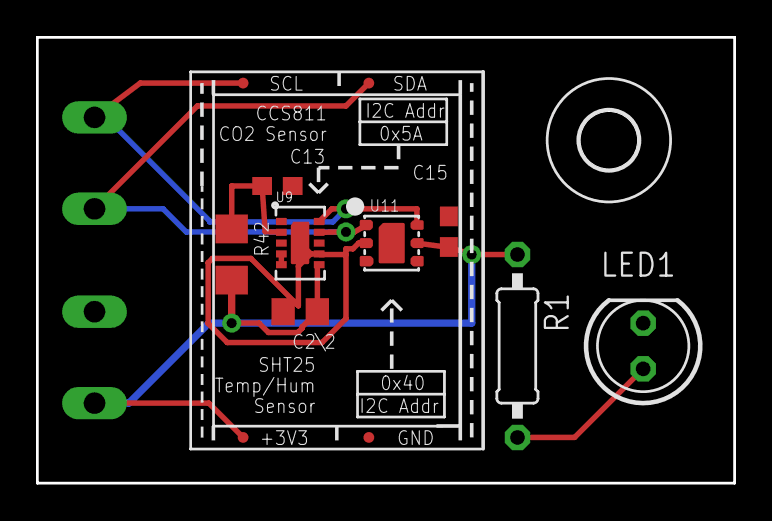
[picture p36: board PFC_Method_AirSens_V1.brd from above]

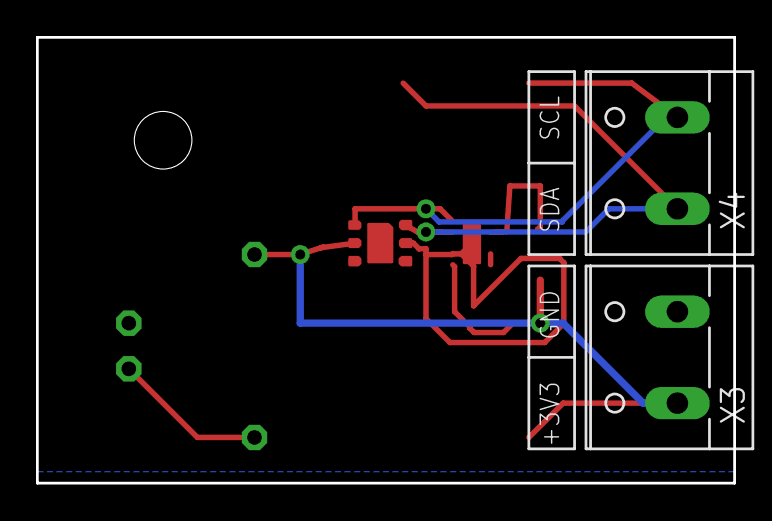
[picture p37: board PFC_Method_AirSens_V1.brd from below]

Board: 2 copper layers, 38.7 x 24.8 mm, 15 parts (2 on the bottom side), 7 nets.

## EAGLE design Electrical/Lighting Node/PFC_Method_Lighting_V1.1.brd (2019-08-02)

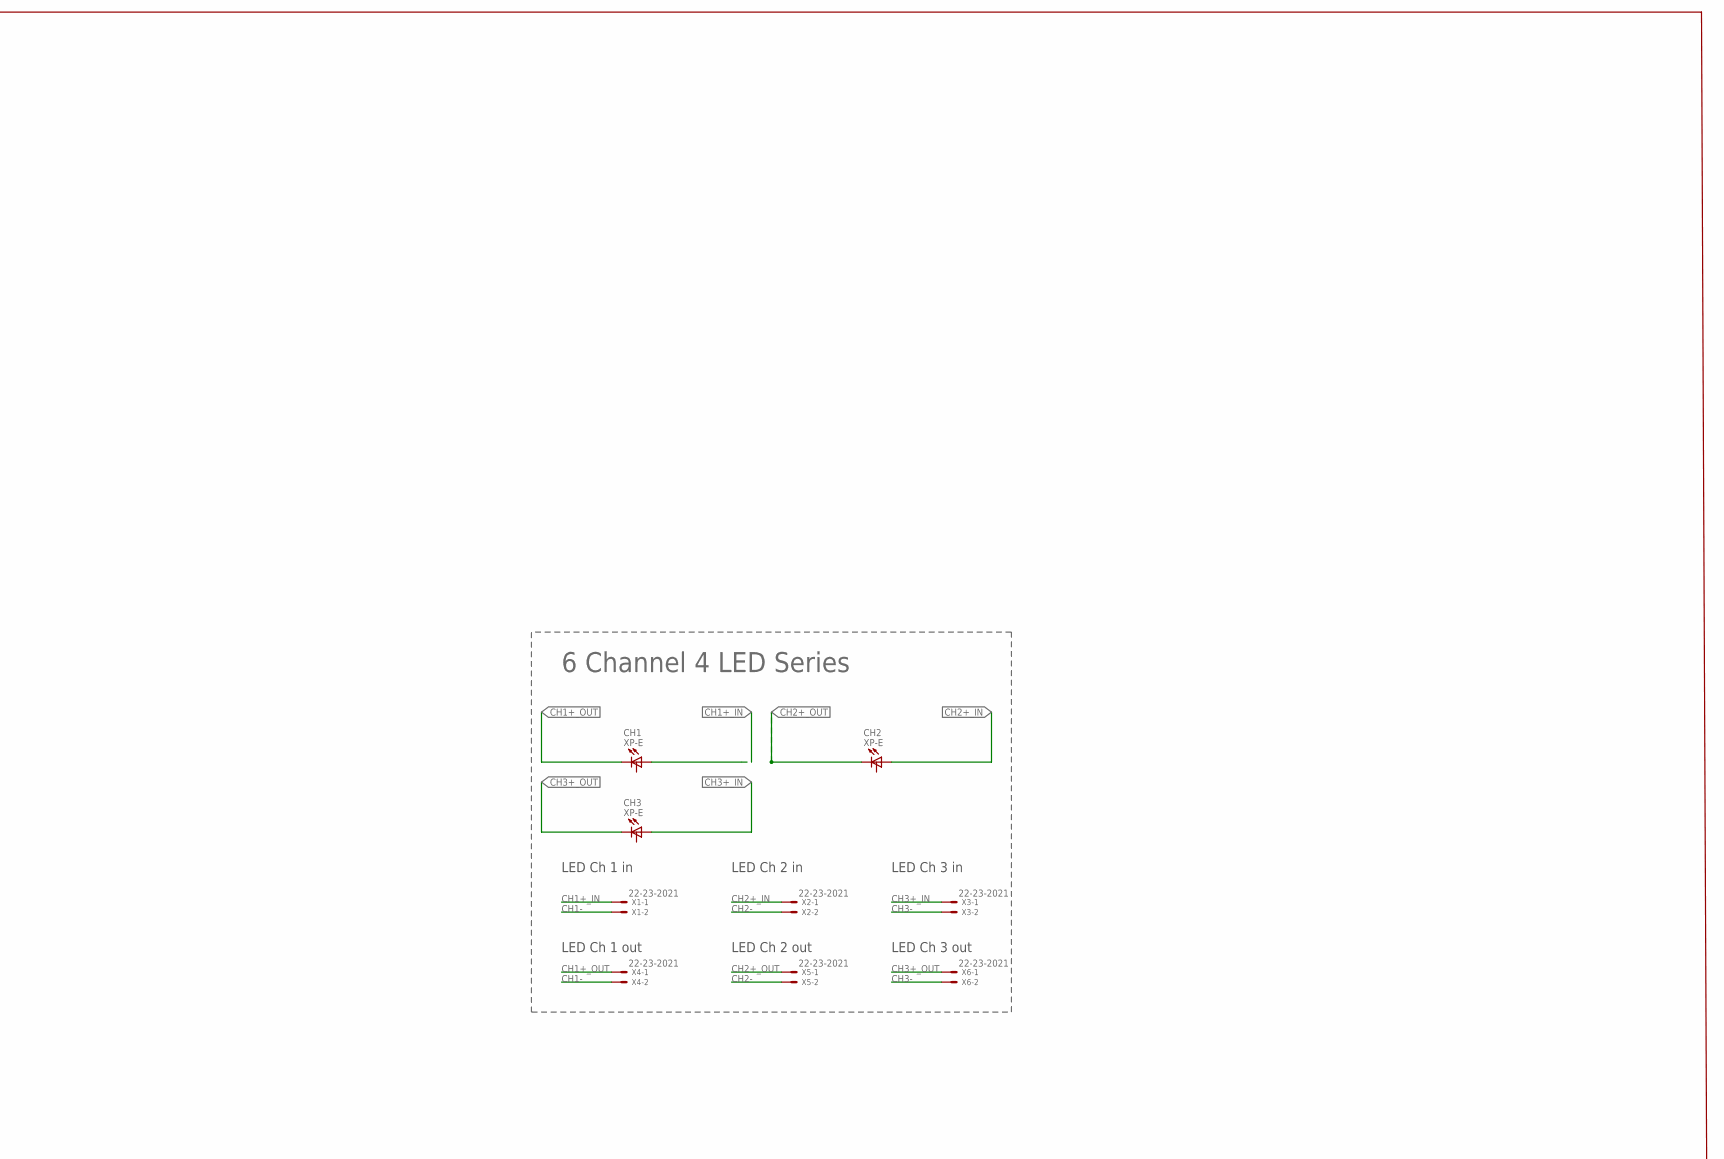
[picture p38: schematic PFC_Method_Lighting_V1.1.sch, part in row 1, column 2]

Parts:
CH1, CH2, CH3: XP-E; CREE-XLAMP-XP-E
X1, X2, X3, X4, X5, X6: 22-23-2021

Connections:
CH1+_IN: CH1.A, CH1.A@1 (A), X1.1
CH1+_OUT: CH1.C, CH1.C@1 (C), X4.1
CH1-: X1.2, X4.2
CH2+_IN: CH2.A, CH2.A@1 (A), X2.1
CH2+_OUT: CH2.C, CH2.C@1 (C), X5.1
CH2-: X2.2, X5.2
CH3+_IN: CH3.A, CH3.A@1 (A), X3.1
CH3+_OUT: CH3.C, CH3.C@1 (C), X6.1
CH3-: X3.2, X6.2

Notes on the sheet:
Original Board by Dan Poitrast
Change Log:
Released under the Creative Commons Attribution Share-Alike 4.0 License https://creativecommons.org/licenses/by-sa/4.0/
6 Channel 4 LED Series
LED Ch 1 out
LED Ch 2 out
LED Ch 3 out
LED Ch 1 in
LED Ch 2 in
LED Ch 3 in

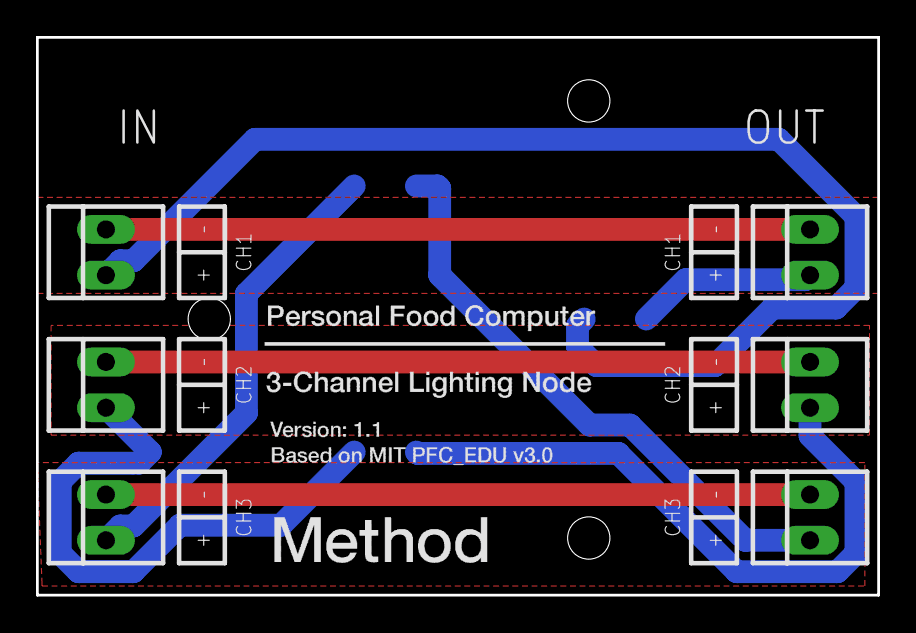
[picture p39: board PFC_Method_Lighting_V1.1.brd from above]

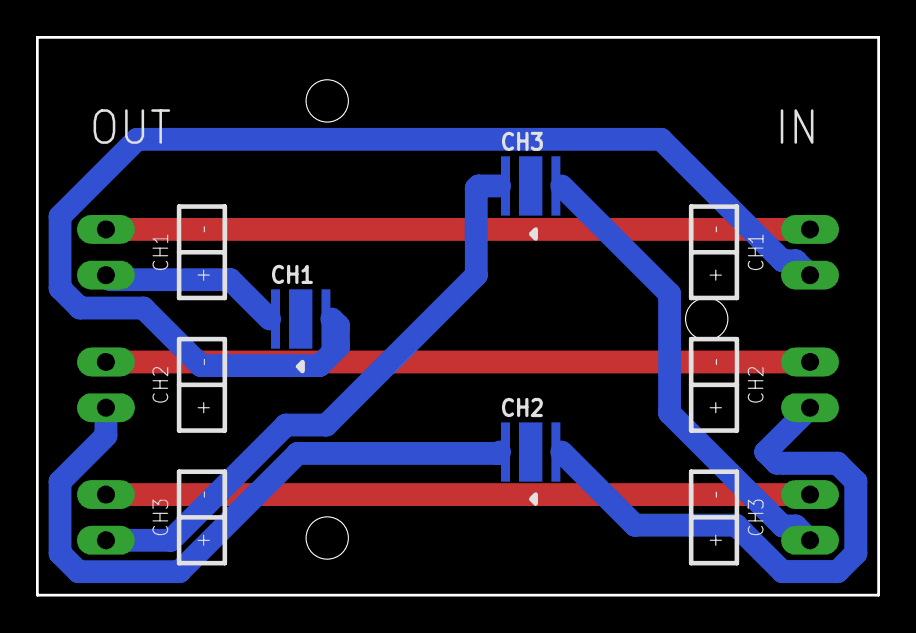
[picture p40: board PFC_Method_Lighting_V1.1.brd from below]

Board: 2 copper layers, 46.7 x 31.0 mm, 9 parts (3 on the bottom side), 9 nets.

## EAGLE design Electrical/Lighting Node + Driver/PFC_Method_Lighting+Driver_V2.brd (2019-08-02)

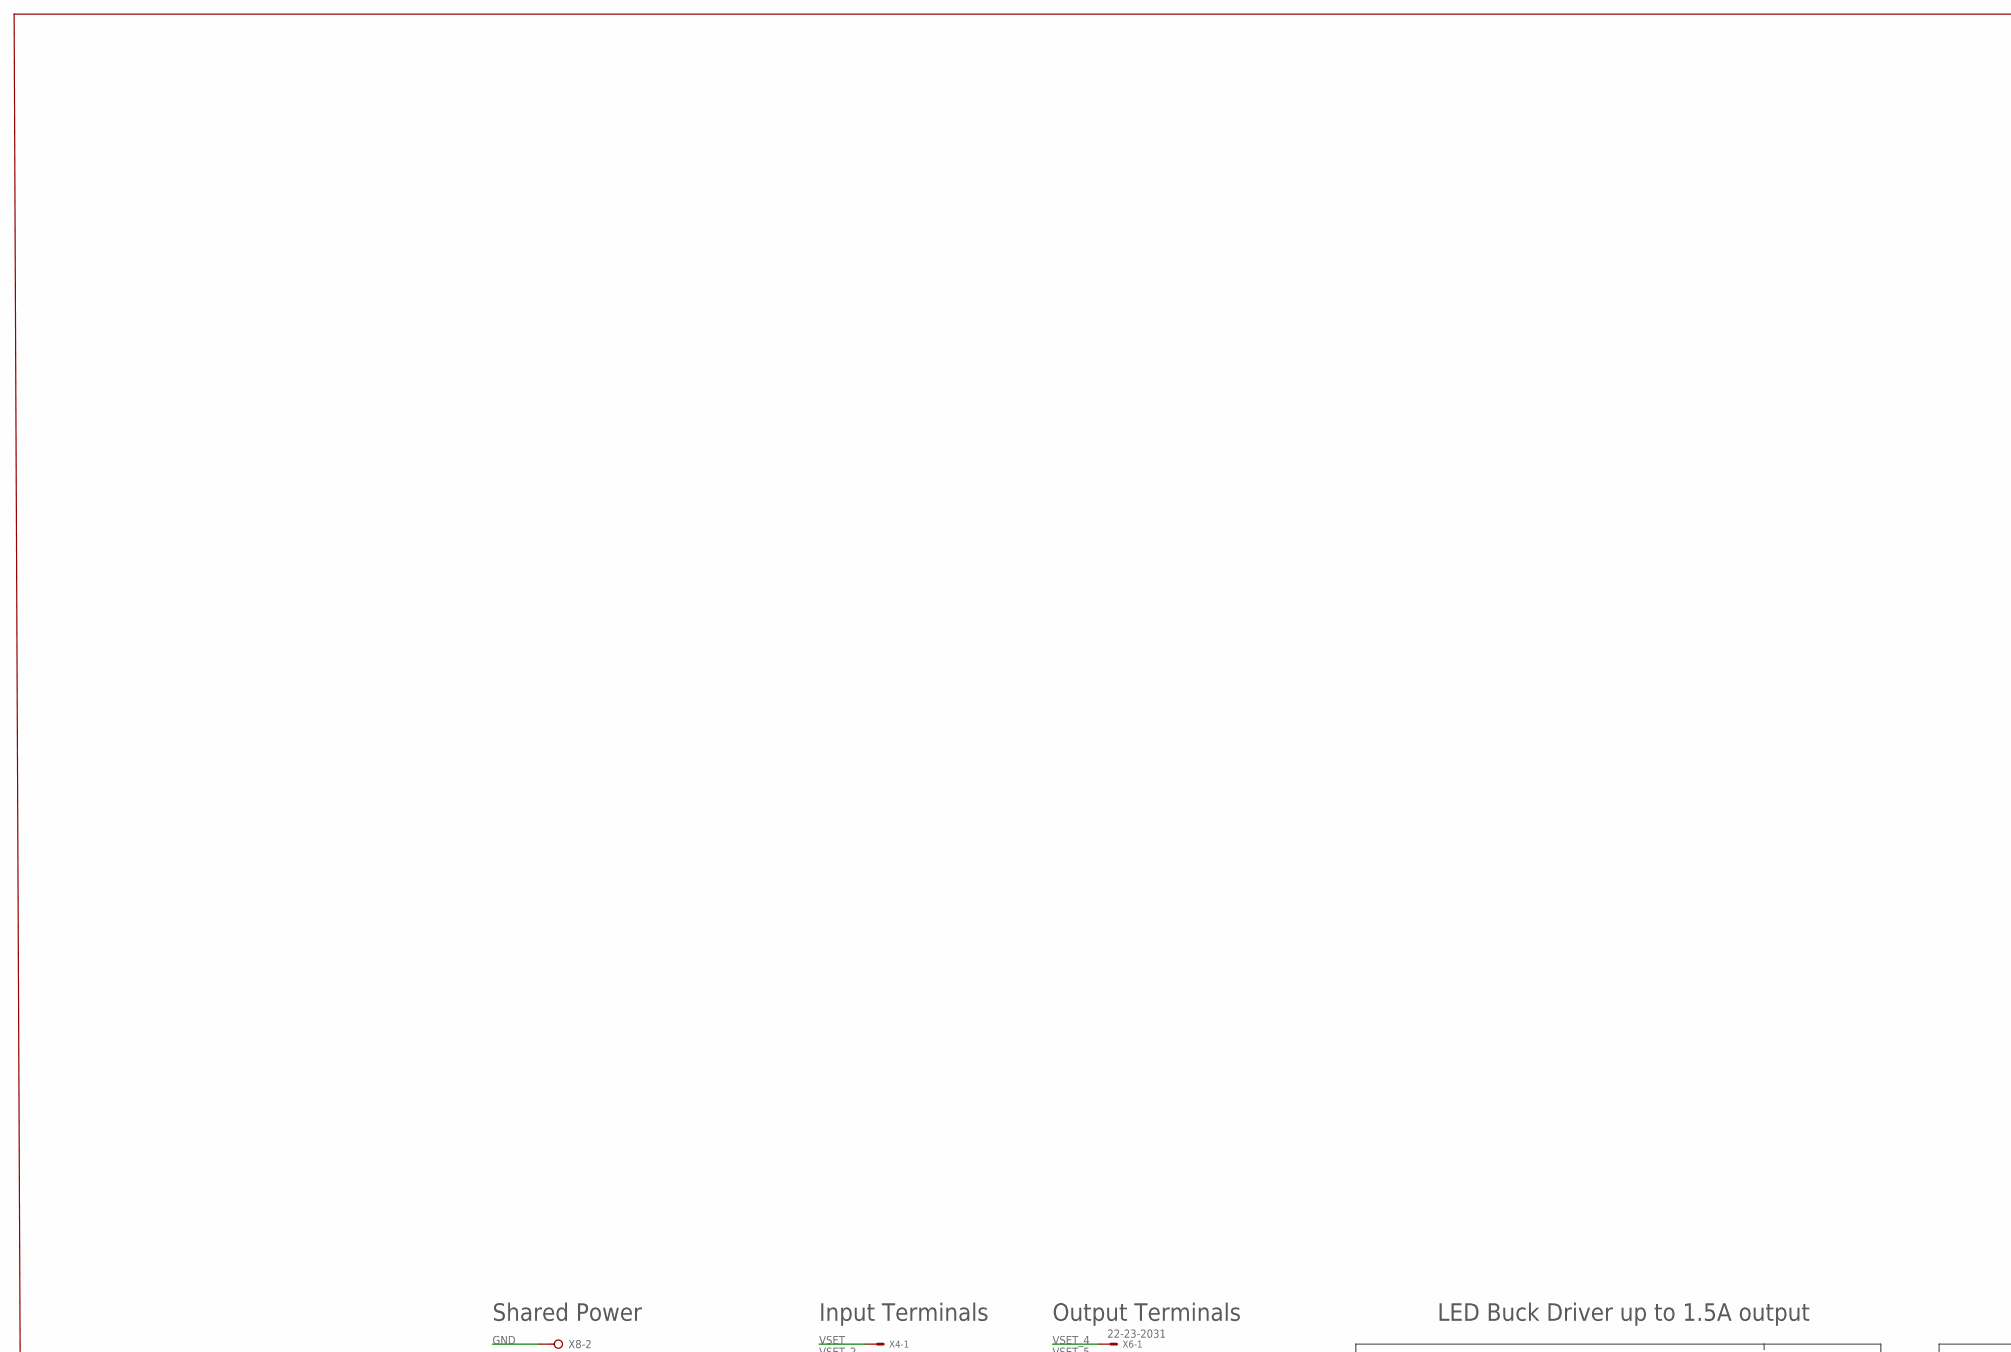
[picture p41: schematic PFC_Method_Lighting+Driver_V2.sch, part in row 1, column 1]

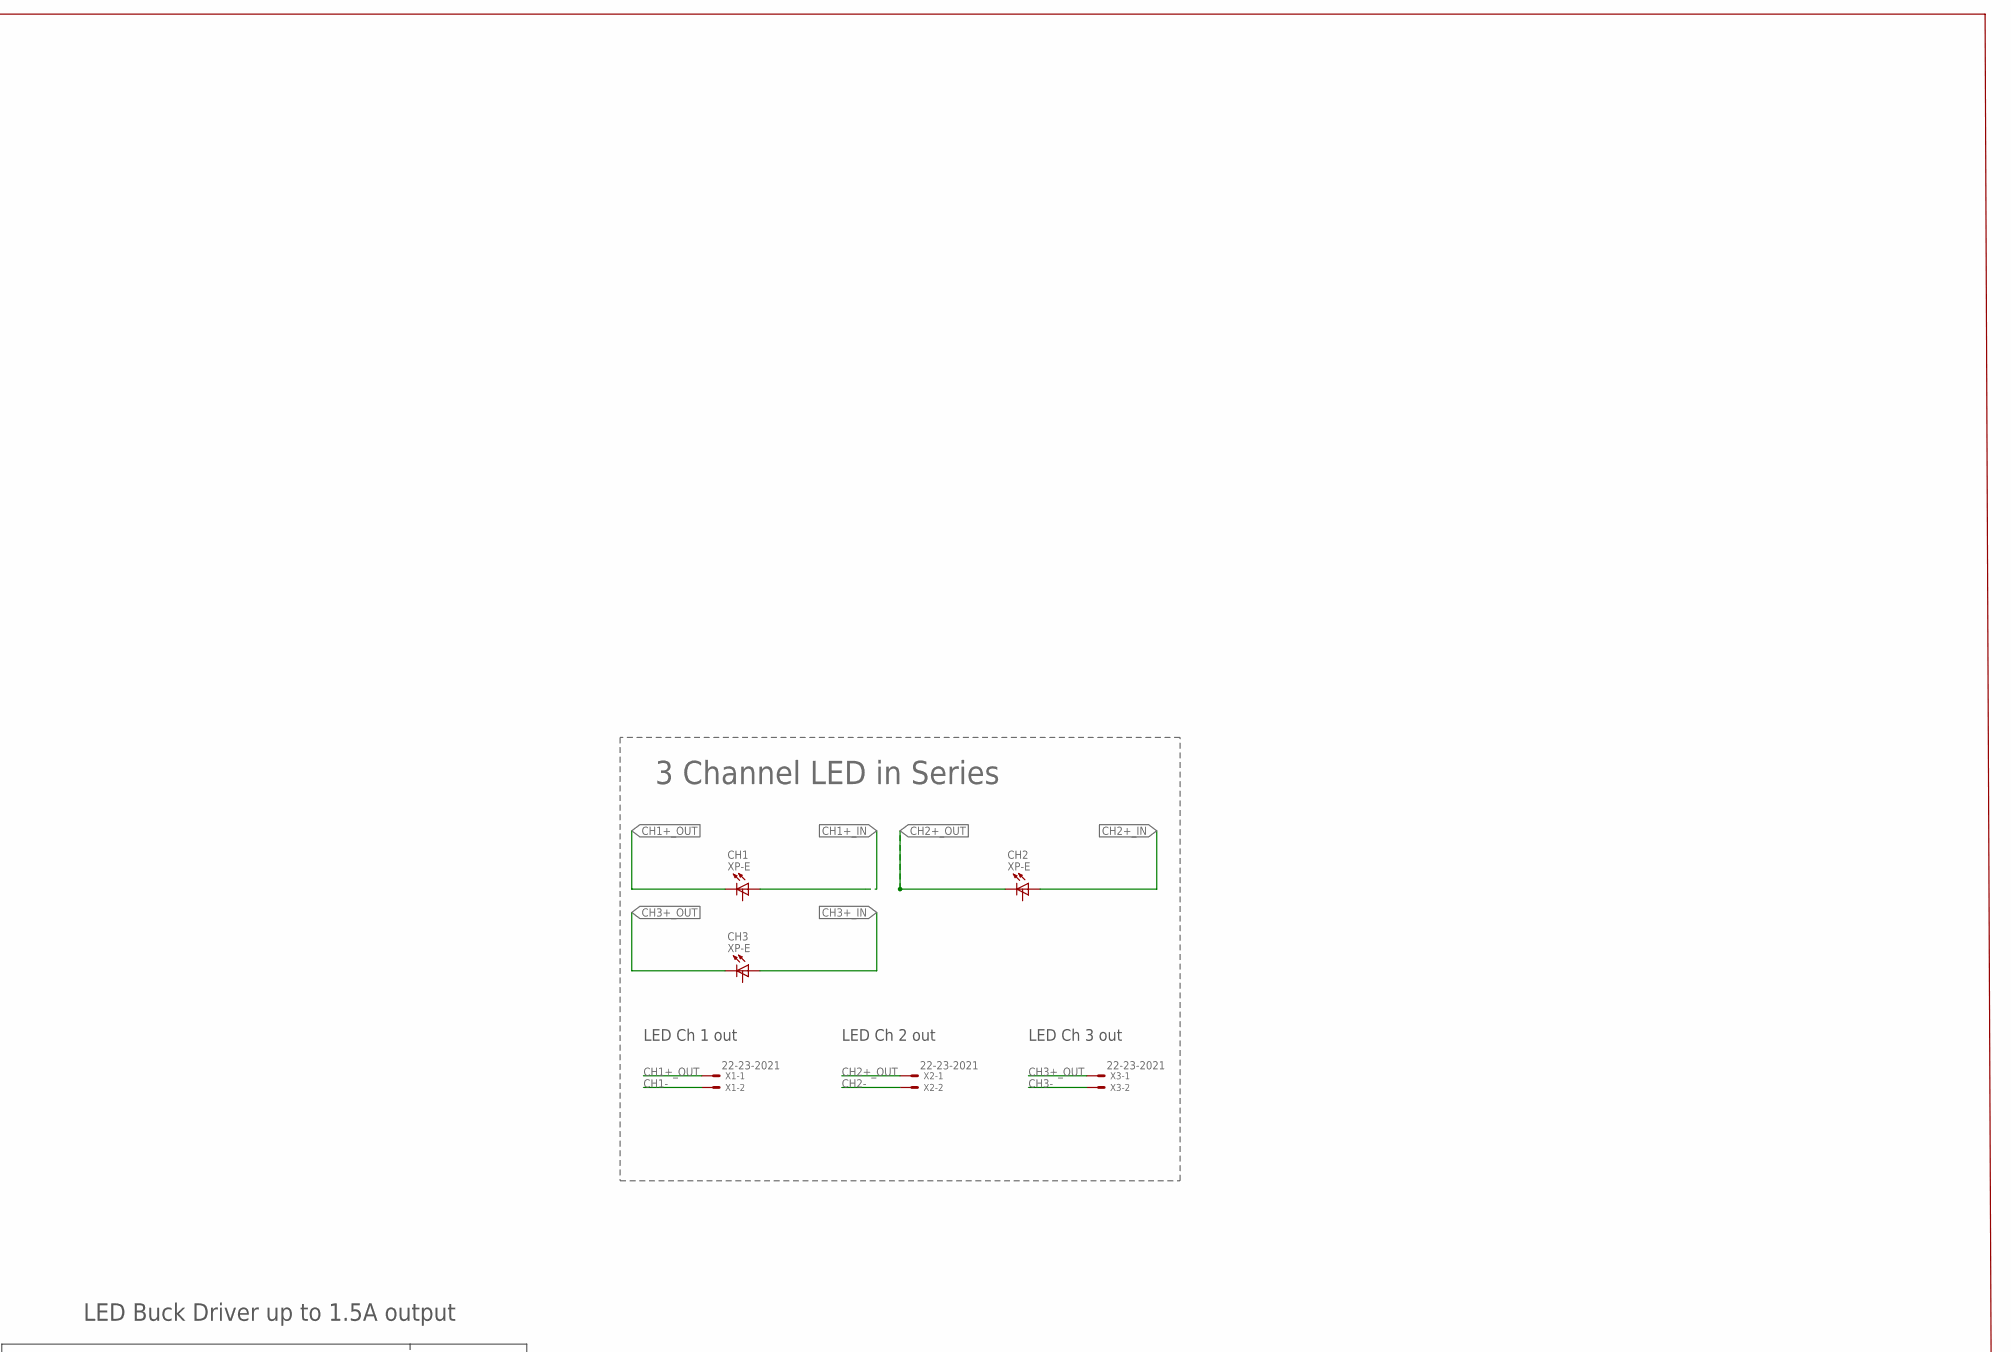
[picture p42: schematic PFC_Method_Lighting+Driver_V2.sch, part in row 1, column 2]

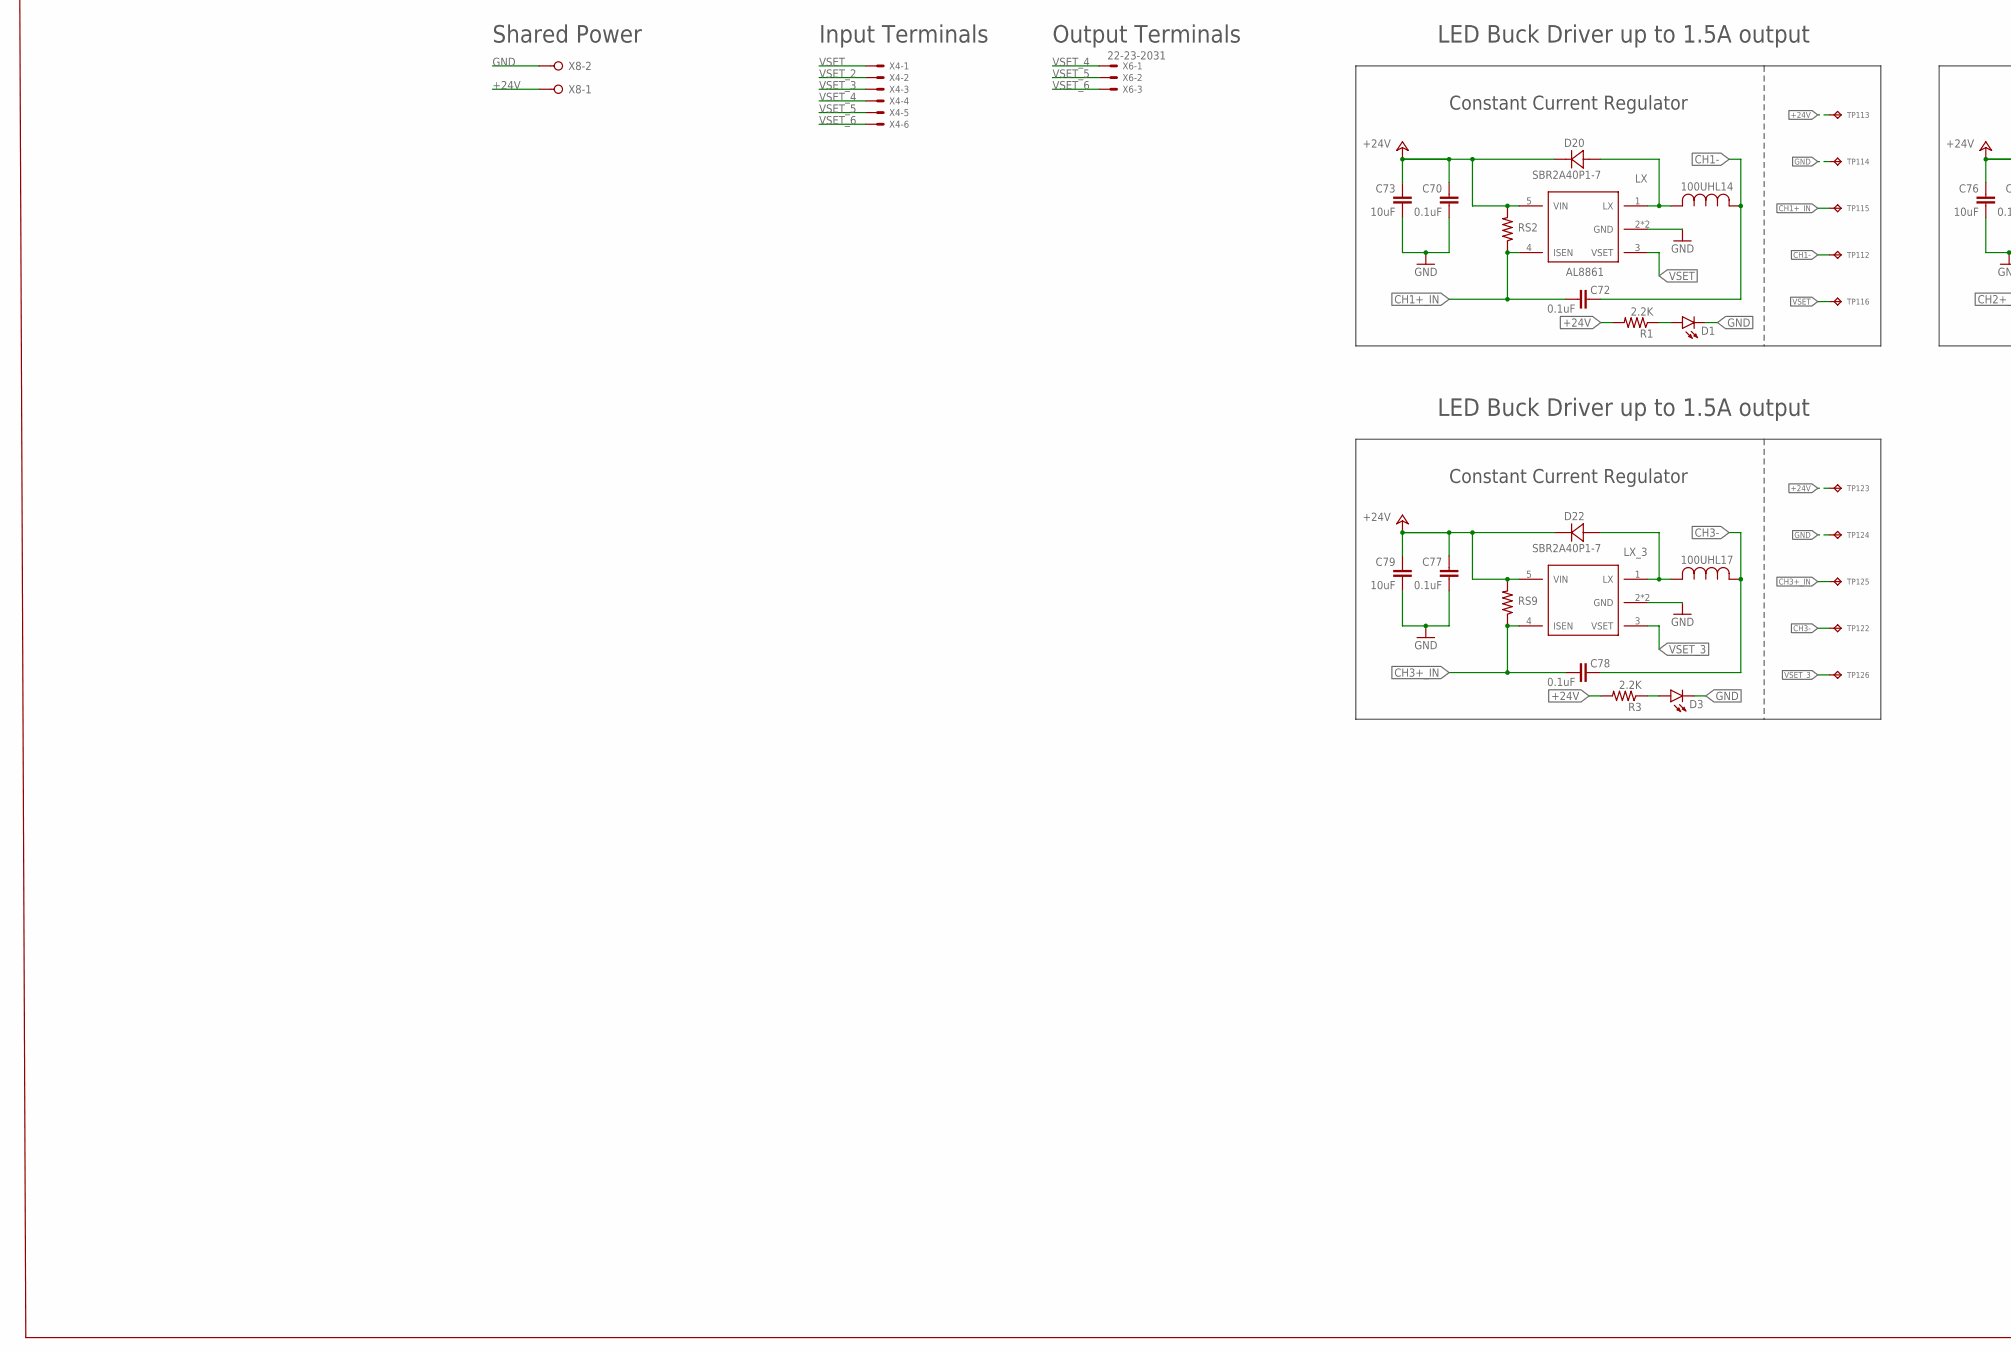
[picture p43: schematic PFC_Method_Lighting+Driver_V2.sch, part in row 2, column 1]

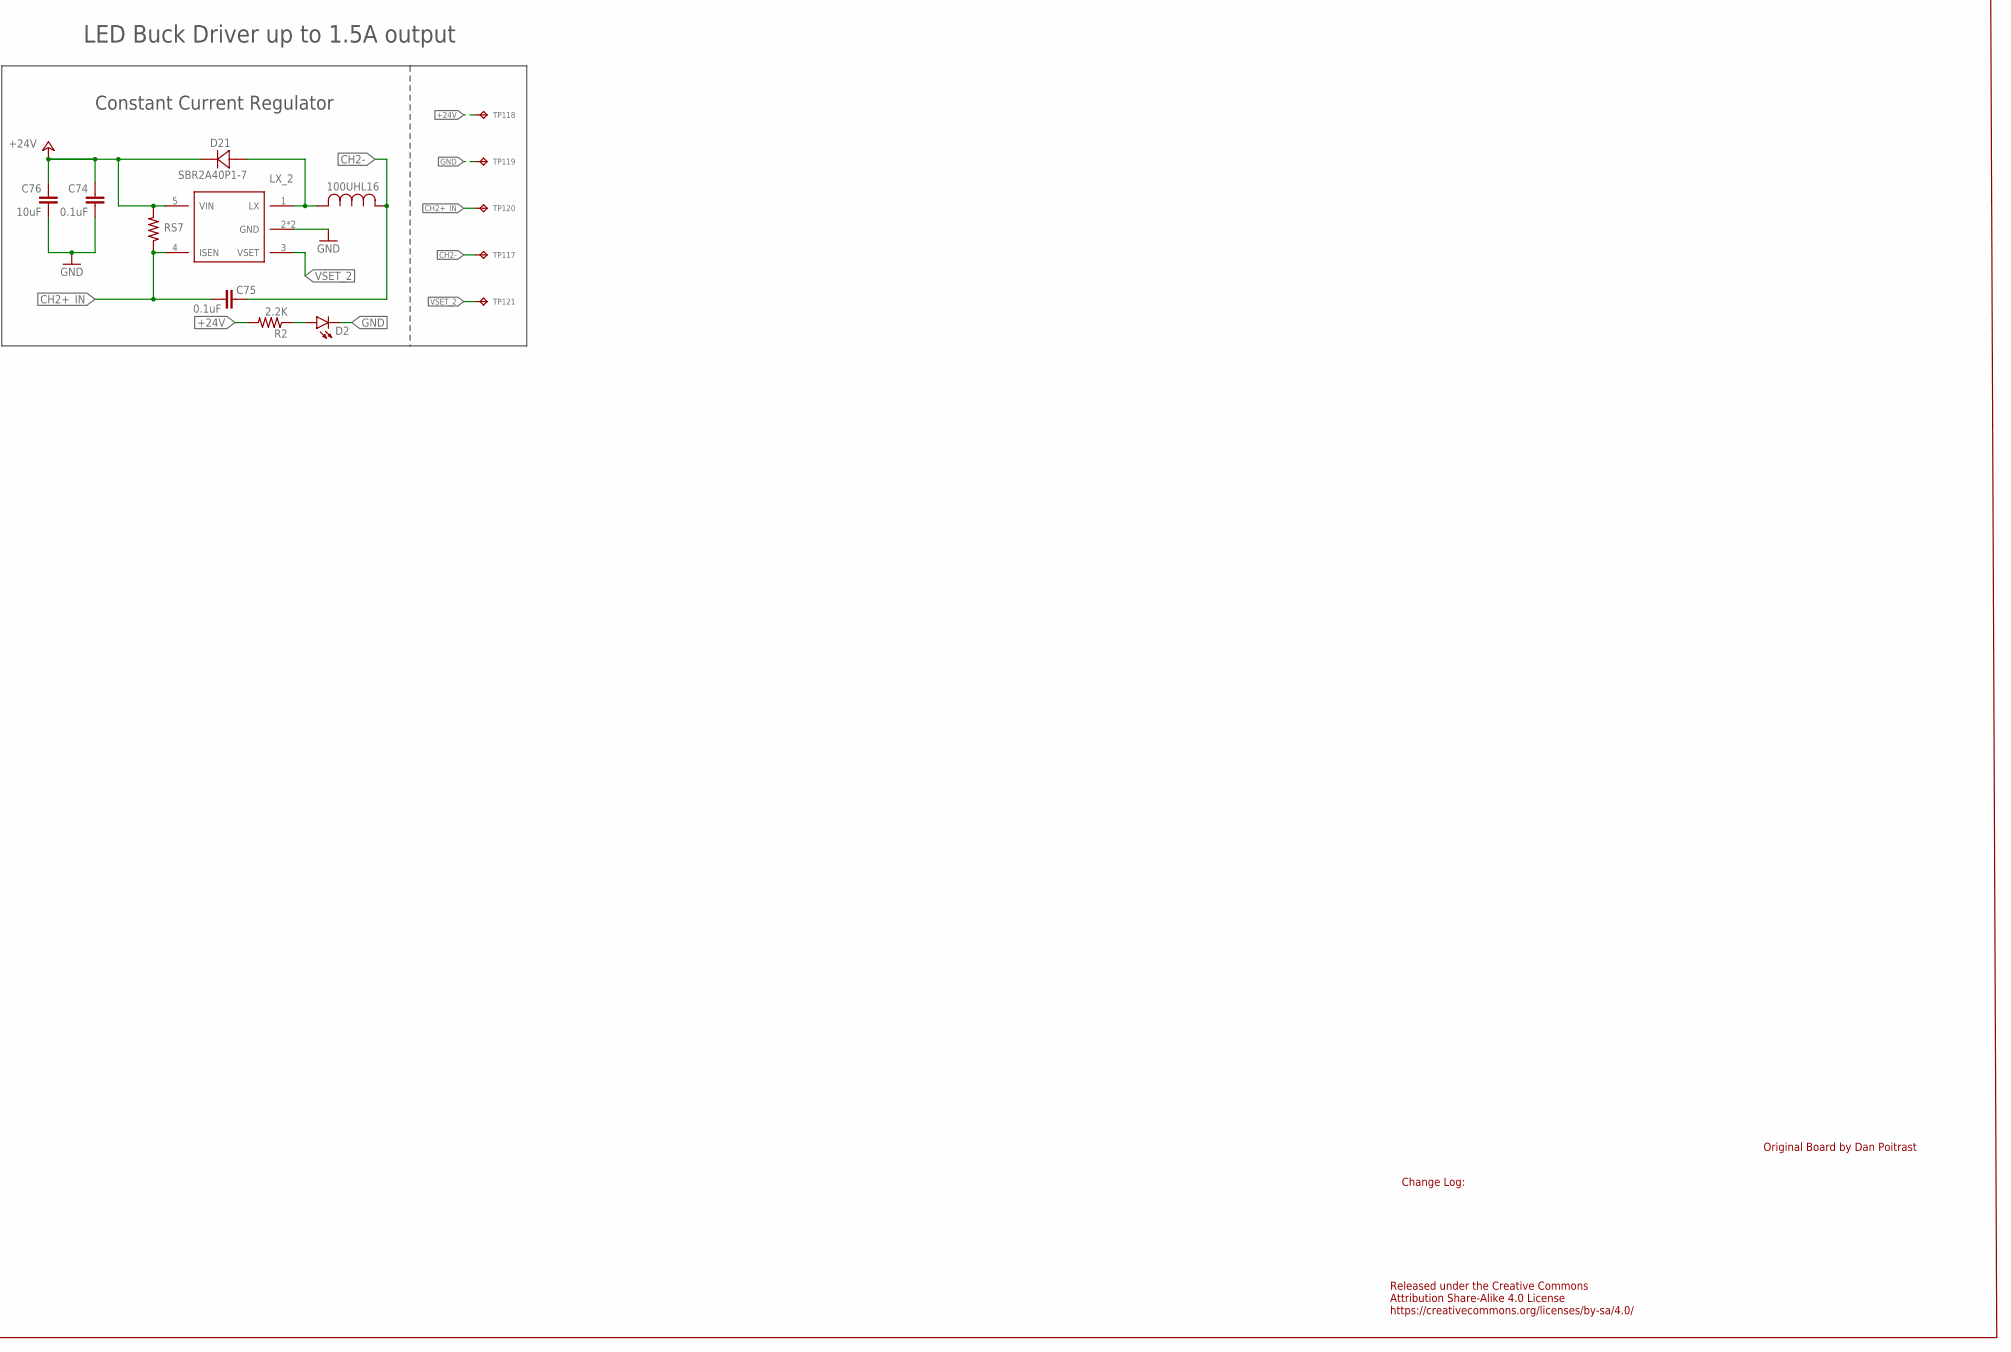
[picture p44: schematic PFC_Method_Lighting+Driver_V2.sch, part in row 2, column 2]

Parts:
C70, C72, C74, C75, C77, C78: 0.1uF; C0603
C73, C76, C79: 10uF; C0805
CH1, CH2, CH3: XP-E; CREE-XLAMP-XP-E
D1, D2, D3: LED5MM; LED_5MM
D20, D21, D22: SBR2A40P1-7; POWERDI123
L14, L16, L17: 100UH; IND_BOURNS_SDR1307
R1, R2, R3: 2.2K; 0207/10
RS2: 6.34Ω; R0805
RS7, RS9: 6.34 Ω; R0805
TP112, TP113, TP114, TP115, TP116, TP117, TP118, TP119, TP120, TP121, TP122, TP123, TP124, TP125, TP126: TPTP06R; TP06R
U$25, U$26, U$27: AL8861
X1, X2, X3: 22-23-2021
X4: 22-23-2061
X6: 22-23-2031
X8: W237-02P; W237-132

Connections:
+24V: C70.1, C73.1, C74.1, C76.1, C77.1, C79.1, D20.-, D21.-, D22.-, R1.2, R2.2, R3.2, RS2.2, RS7.2, RS9.2, TP113.TP, TP118.TP, TP123.TP, U$25.5 (VIN), U$26.5 (VIN), U$27.5 (VIN), X8.1
CH1+_IN: C72.2, CH1.A, CH1.A@1 (A), RS2.1, TP115.TP, U$25.4 (ISEN)
CH1+_OUT: CH1.C, CH1.C@1 (C), X1.1
CH1-: C72.1, L14.2, TP112.TP, X1.2
CH2+_IN: C75.2, CH2.A, CH2.A@1 (A), RS7.1, TP120.TP, U$26.4 (ISEN)
CH2+_OUT: CH2.C, CH2.C@1 (C), X2.1
CH2-: C75.1, L16.2, TP117.TP, X2.2
CH3+_IN: C78.2, CH3.A, CH3.A@1 (A), RS9.1, TP125.TP, U$27.4 (ISEN)
CH3+_OUT: CH3.C, CH3.C@1 (C), X3.1
CH3-: C78.1, L17.2, TP122.TP, X3.2
GND: C70.2, C73.2, C74.2, C76.2, C77.2, C79.2, D1.K (C), D2.K (C), D3.K (C), TP114.TP, TP119.TP, TP124.TP, U$25.2 (GND), U$25.44 (GND), U$26.2 (GND), U$26.44 (GND), U$27.2 (GND), U$27.44 (GND), X8.2
LX: D20.+, L14.1, U$25.1 (LX)
LX_2: D21.+, L16.1, U$26.1 (LX)
LX_3: D22.+, L17.1, U$27.1 (LX)
unnamed: D2.A, R2.1
unnamed: D1.A, R1.1
unnamed: D3.A, R3.1
VSET: TP116.TP, U$25.3 (VSET), X4.1
VSET_2: TP121.TP, U$26.3 (VSET), X4.2
VSET_3: TP126.TP, U$27.3 (VSET), X4.3
VSET_4: X4.4, X6.1
VSET_5: X4.5, X6.2
VSET_6: X4.6, X6.3

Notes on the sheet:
Original Board by Dan Poitrast
Change Log:
Released under the Creative Commons Attribution Share-Alike 4.0 License https://creativecommons.org/licenses/by-sa/4.0/
3 Channel LED in Series
LED Buck Driver up to 1.5A output
Constant Current Regulator
LED Ch 1 out
LED Ch 2 out
LED Ch 3 out
Input Terminals
Output Terminals
Shared Power
AL8861

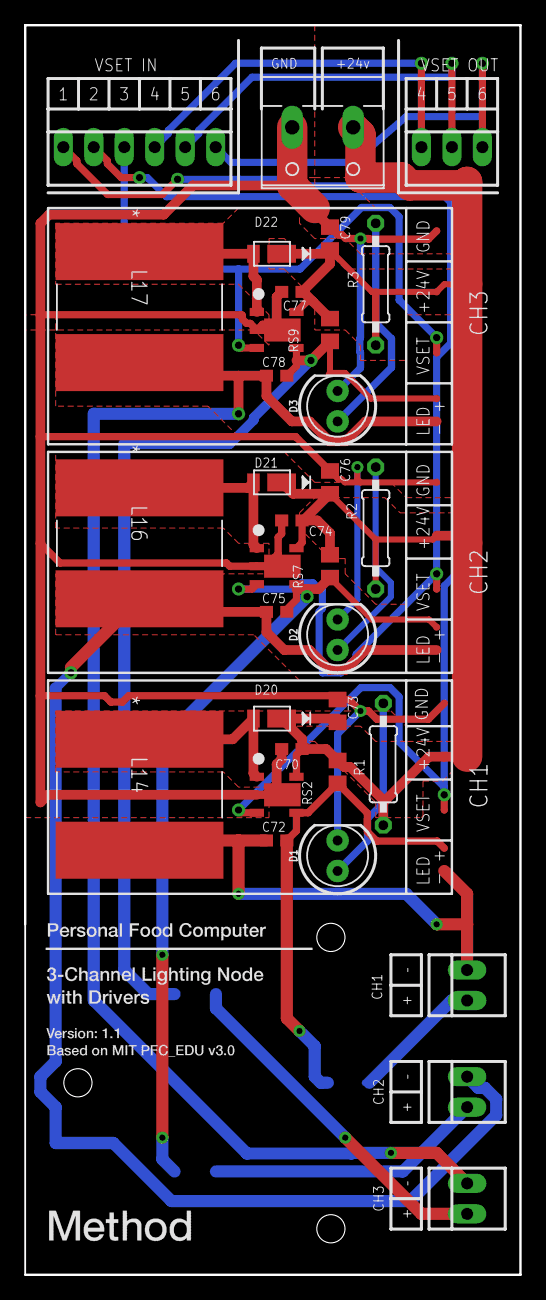
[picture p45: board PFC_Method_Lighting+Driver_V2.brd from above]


Board: 2 copper layers, 41.3 x 104.1 mm, 51 parts (3 on the bottom side), 23 nets.

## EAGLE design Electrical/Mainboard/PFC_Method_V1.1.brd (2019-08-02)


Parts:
C2, C4, C7, C10, C12, C17, C18, C19, C20, C21, C23, C24, C25, C26, C27: 0.1uF; C0603
C3: .1uF; C0603@1
C22: 10uF; C0805
C30: 4.7uF; C0805
D2, D3, D4, D8: APT1608; CHIPLED_0603
F1: 400mA; 0603
F12: GSH15
IC2: MCP23017SO; SO28W
J1, J5, J6: 5-1634503-1; CONN5_5-1634503-1
J2, J3, J16, J17: GROVE_4PIN_CONNECTOR
J7: UJ2-AV-1-SMT; CUI_UJ2-AV-1-SMT
J8, J9, J10: ATLAS-STAMP
J12, J13, J14, J15, J20: CONN_04; 1X04
J18, J19: CONN_08"; 1X08
JP1, JP2, JP3, JP4, JP5, JP6, JP7, JP8, JP9: JP2E; JP2
L1: 5V; LM2596
L2: 12V; LM2596
R1, R15, R16, R42, R47: 10K; R0603
R2, R3, R4, R5, R6, R7, R8, R9: 10K; 0603-RES
R10: 1.2K; RC0603N
R11: 550Ω; RC0603N
R12: 2.2K; RC0603N
R13, R14, R48, R49: 10K; R0805W
R17, R18, R19, R20, R21, R22, R23, R24, R25, R26, R27, R28, R29, R30, R31, R32, R33, R34, R35, R36, R37, R38, R39, R40, R41, R43, R45, R46, R88, R90, R117, R118, R119, R120, R121, R122: 1K; RC0603N
R44: 330Ω; RC0603N
SJ_A1, SJ_A2, SJ_A3: SOLDERJUMPERREFLOW_NOPASTE; SJ1
T3, T4: NMOSSOT23; SOT-23
TP1, TP3, TP4, TP5, TP6, TP7, TP104, TP105: TPTP04R; TP04R
TP2: TPTP06R; TP06R
U1: TCA9548APWRPW24-M; PW24-M
U2, U6, U8: RM-3.33.3S; RM3.33.3S-SIP4
U3, U4, U14: ISO1540; D8
U17: LM2937-3.3V; MP04A
U18: DAC5578; TSSOP16
U$3: PJ-036AH; BARREL-JACK-PJ-036AH
U$5, U$6: USB_RIGHT
X1: MINI-USB-32005-201; 32005-201
X2, X3, X5, X8: W237-02P; W237-132
X4: 22-23-2061

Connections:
24V_IN: F12.1, U$3.1
!LDAC!: R90.2, SJ_A3.2, TP104.1, U18.1 (!LDAC!)
+3V3: C2.1, C3.1, C10.1, C17.1, C19.1, C23.1, C25.1, C26.1, C30.1, F1.2, JP1.1, JP2.1, JP3.1, JP4.1, JP5.1, JP6.1, JP7.1, JP8.1, JP9.1, R1.2, R2.2, R4.2, R6.2, R8.2, R9.2, R33.2, R35.2, R37.2, R39.2, R41.2, R42.2, R44.2, R45.2, R47.2, R88.1, R90.1, R117.2, R118.2, R119.2, R120.2, R121.2, R122.2, SJ_A1.1, TP2.TP, U1.24 (VCC), U2.2 (+VIN), U3.1 (VCC1), U4.1 (VCC1), U6.2 (+VIN), U8.2 (+VIN), U14.1 (VCC1), U18.3 (AVDD), U18.8 (VREF_IN), X1.1
+5V: C21.1, J20.4, JP1.3, JP2.3, JP3.3, JP4.3, JP5.3, JP6.3, JP7.3, JP8.3, JP9.3, L1.OUT+, R11.2, TP3.1, U17.1 (IN), X3.1
+12V: L2.OUT+, R10.2, TP1.1, X2.1, X8.1
+24V: F12.2, L1.IN+, L2.IN+, R12.2, TP4.1, X5.1
A0_EXT_1: R4.1, R5.2, U1.1 (A0)
A1_EXT_1: R6.1, R7.2, U1.2 (A1)
A2_EXT_1: R2.1, R3.2, U1.21 (A2)
ADDR0: SJ_A1.2, SJ_A2.2, U18.2 (ADDR0)
D+: J7.2, U$5.PIN2, U$6.PIN2
D-: J7.3, U$5.PIN3, U$6.PIN3
DAC_!CLR!: R88.2, TP105.1, U18.9 (!CLR!)
GND: D4.C, L1.IN-, L2.IN-, TP5.1, U$3.2, U$3.3, X5.2
GND_(12V): D2.C, L2.OUT-, TP7.1, X2.2, X8.2
GND_LOGIC: C2.2, C3.2, C7.2, C10.2, C17.2, C19.2, C21.2, C22.2, C23.2, C25.2, C26.2, C30.2, D3.C, D8.C, IC2.10 (VSS), J2.P$4 (4), J3.P$4 (4), J7.4, J7.SH1 (SHIELD), J7.SH2 (SHIELD), J12.4, J13.4, J14.4, J15.4, J16.P$4 (4), J17.P$4 (4), J20.3, L1.OUT-, R3.1, R5.1, R7.1, R13.2, R48.2, SJ_A2.1, SJ_A3.1, T3.2 (S), T4.2 (S), TP6.1, U1.12 (GND), U2.1 (-VIN), U3.4 (GND1), U4.4 (GND1), U6.1 (-VIN), U8.1 (-VIN), U14.4 (GND1), U17.2 (GND), U17.4 (TAB), U18.14 (GND), U$5.GND1 (CHASIS), U$5.GND2 (CHASIS), U$5.GND3 (CHASIS), U$5.GND4 (CHASIS), U$6.GND1 (CHASIS), U$6.GND2 (CHASIS), U$6.GND3 (CHASIS), U$6.GND4 (CHASIS), X1.4, X1.5, X3.2
I2C_VCC_1: J16.P$3 (3), JP1.2
I2C_VCC_2: J17.P$3 (3), JP2.2
I2C_VCC_3: J2.P$3 (3), JP3.2
I2C_VCC_4: J3.P$3 (3), JP4.2
I2C_VCC_5: J12.3, JP5.2
I2C_VCC_6: J13.3, JP6.2
I2C_VCC_7: J14.3, JP7.2
I2C_VCC_8: J15.3, JP8.2
ISO_3V3_2: C4.1, C12.1, J9.4 (VCC), R34.2, R36.2, U2.4 (+VOUT), U3.8 (ISO_VCC2)
ISO_3V3_3: C18.1, C20.1, J10.4 (VCC), R38.2, R40.2, U4.8 (ISO_VCC2), U6.4 (+VOUT)
ISO_3V3_4: C24.1, C27.1, J8.4 (VCC), R43.2, R46.2, U8.4 (+VOUT), U14.8 (ISO_VCC2)
ISO_GND_2: C4.2, C12.2, J9.3 (GND), U2.3 (-VOUT), U3.5 (ISO_GND2)
ISO_GND_3: C18.2, C20.2, J10.3 (GND), U4.5 (ISO_GND2), U6.3 (-VOUT)
ISO_GND_4: C24.2, C27.2, J8.3 (GND), U8.3 (-VOUT), U14.5 (ISO_GND2)
ISO_SCL_2: J9.1 (RX/SCL), R36.1, U3.6 (ISO_SCL2)
ISO_SCL_3: J10.1 (RX/SCL), R40.1, U4.6 (ISO_SCL2)
ISO_SCL_4: J8.1 (RX/SCL), R46.1, U14.6 (ISO_SCL2)
ISO_SDA_2: J9.2 (TX/SDA), R34.1, U3.7 (ISO_SDA2)
ISO_SDA_3: J10.2 (TX/SDA), R38.1, U4.7 (ISO_SDA2)
ISO_SDA_4: J8.2 (TX/SDA), R43.1, U14.7 (ISO_SDA2)
unnamed: R13.1, R14.1, T4.3 (G)
unnamed: D3.A, R11.1
unnamed: R48.1, R49.1, T3.3 (G)
unnamed: D4.A, R12.1
unnamed: T3.1 (D), U$6.PIN4
unnamed: IC2.21 (GPA0), R17.2
unnamed: IC2.22 (GPA1), R18.2
unnamed: T4.1 (D), U$5.PIN4
unnamed: IC2.23 (GPA2), R19.2
unnamed: IC2.24 (GPA3), R20.2
unnamed: IC2.25 (GPA4), R21.2
unnamed: D2.A, R10.1
unnamed: IC2.26 (GPA5), R22.2
unnamed: IC2.27 (GPA6), R23.2
unnamed: IC2.28 (GPA7), R24.2
unnamed: J18.1, R17.1
unnamed: J18.2, R18.1
unnamed: J18.3, R19.1
unnamed: J18.4, R20.1
unnamed: J18.5, R21.1
unnamed: J18.6, R22.1
unnamed: J18.7, R23.1
unnamed: J18.8, R24.1
unnamed: J19.8, R25.2
unnamed: J19.7, R26.2
unnamed: J19.6, R27.2
unnamed: J19.5, R28.2
unnamed: J19.4, R29.2
unnamed: J19.3, R30.2
unnamed: J19.2, R31.2
unnamed: J19.1, R32.2
unnamed: IC2.8 (GPB7), R25.1
unnamed: IC2.7 (GPB6), R26.1
unnamed: IC2.6 (GPB5), R27.1
unnamed: IC2.5 (GPB4), R28.1
unnamed: IC2.4 (GPB3), R29.1
unnamed: IC2.3 (GPB2), R30.1
unnamed: IC2.2 (GPB1), R31.1
unnamed: IC2.1 (GPB0), R32.1
unnamed: D8.A, R44.1
unnamed: C22.1, F1.1, U17.3 (OUT)
PGND_2: J1.2, J1.3, J1.4, J1.5, J9.6 (PGND)
PGND_3: J6.2, J6.3, J6.4, J6.5, J10.6 (PGND)
PGND_4: J5.2, J5.3, J5.4, J5.5, J8.6 (PGND)
PRB_2: J1.1, J9.5 (PBR)
PRB_3: J6.1, J10.5 (PBR)
PRB_4: J5.1, J8.5 (PBR)
RESET1: R1.1, U1.3 (!RESET)
SC0: U1.5 (SC0)
SC1: IC2.12 (SCL), R16.1, U1.7 (SC1)
SC2: R47.1, U1.9 (SC2), X1.3
SC3: U1.11 (SC3), U18.16 (SCL)
SC4: U1.14 (SC4)
SC5: J12.1, J13.1, J14.1, J15.1, U1.16 (SC5)
SC6: R33.1, R37.1, R41.1, U1.18 (SC6), U3.3 (SCL1), U4.3 (SCL1), U14.3 (SCL1)
SC7: J2.P$1 (1), J3.P$1 (1), J16.P$1 (1), J17.P$1 (1), U1.20 (SC7)
SCL: J20.1, R8.1, U1.22 (SCL)
SD0: U1.4 (SD0)
SD1: IC2.13 (SDA), R15.1, U1.6 (SD1)
SD2: R42.1, U1.8 (SD2), X1.2
SD3: U1.10 (SD3), U18.15 (SDA)
SD4: U1.13 (SD4)
SD5: J12.2, J13.2, J14.2, J15.2, U1.15 (SD5)
SD6: R35.1, R39.1, R45.1, U1.17 (SD6), U3.2 (SDA1), U4.2 (SDA1), U14.2 (SDA1)
SD7: J2.P$2 (2), J3.P$2 (2), J16.P$2 (2), J17.P$2 (2), U1.19 (SD7)
SDA: J20.2, R9.1, U1.23 (SDA)
USB1: R49.2, U18.12 (VOUT_D)
USB2: R14.2, U18.13 (VOUT_B)
V+: J7.1, U$5.PIN1, U$6.PIN1
VCC_IN_MCP: C7.1, IC2.9 (VDD), IC2.18 (!RESET), JP9.2, R15.2, R16.2
VSET: R117.1, U18.7 (VOUT_G), X4.1
VSET_2: R118.1, U18.6 (VOUT_E), X4.2
VSET_3: R119.1, U18.5 (VOUT_C), X4.3
VSET_4: R120.1, U18.4 (VOUT_A), X4.4
VSET_5: R121.1, U18.10 (VOUT_H), X4.5
VSET_6: R122.1, U18.11 (VOUT_F), X4.6

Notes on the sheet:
I2C Pull-up Resistors
I2C Address Select IO Ext 1
5-26V to 3.3V@400mA Regulator w/3v3 Enable, Indicator LED & Fuse
Notes: - GND !LDAC! for syncronous mode - Broadcast I2C Addr = 0x47 - ADDR0=Low, I2C Addr=0x48 - ADDR0=High, I2C Addr=0x4A - ADDR0=Float, I2C Addr=0x4C
Testpads
DAC Signal Pullups
DAC Address Set
DAC HW Enable
3.3V Isolator
I2C Isolator
Atlas Stamp
BNC Connector
Atlas Sensor Port
Air Sensor I/O
USB Mini Jack
Input Terminals
Lighting I/O
Relay Switches
I2C I/O Addons
I2C Channel 7: Grove Connectors
I2C Channel 5
Headers to Relay Control Board 1
Headers to Relay Control Board 2
Voltage Select



Board: 2 copper layers, 105.5 x 103.0 mm, 147 parts (35 on the bottom side), 108 nets.

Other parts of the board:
U$1, U$2, U$7, U$8: 3,2

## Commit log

2019-05-31 All components in Rhino and STL for printing
    [B.01.A - Bottom Corner Connector, Left (1 of 2).stl, B.01.A - Bottom Corner Connector, Left (2 of 2).stl, B.01.A - Bottom Corner Connector, Left.3dm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]
2019-08-02 Added safety mount
    [B.11 - Bottom Module – Safety Cover – Mount Piece L.stl, B.11 - Bottom Module – Safety Cover – Mount Piece R.stl, B.11 - Bottom Module – Safety Cover.stl]

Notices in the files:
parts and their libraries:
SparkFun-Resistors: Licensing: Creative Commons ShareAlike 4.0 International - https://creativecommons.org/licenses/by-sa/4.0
